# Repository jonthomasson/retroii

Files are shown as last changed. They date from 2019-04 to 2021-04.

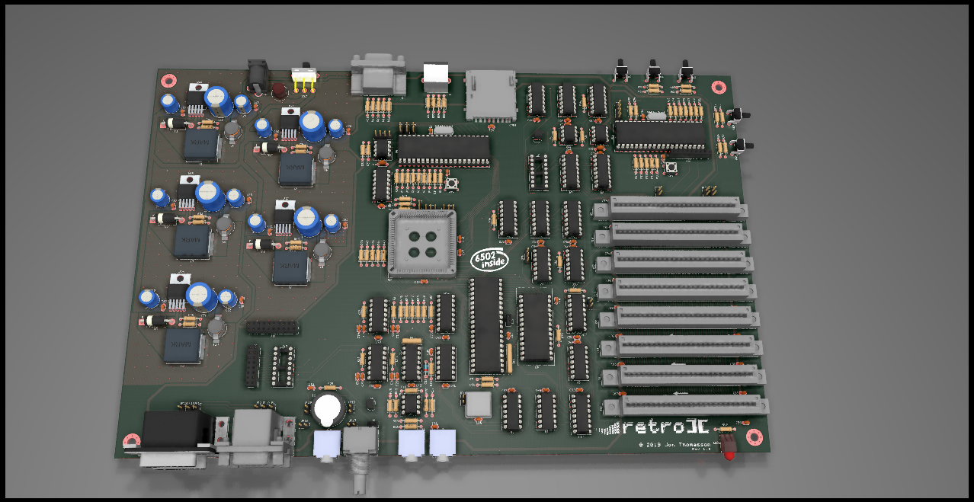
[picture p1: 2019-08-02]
rev1.a/retroii/pics/retroii_3d_front.png

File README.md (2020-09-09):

# retroii
Retro ][ is a 6502 based computer based off of the Apple ][. 

Growing up in the 80's I was part of an amazing and special time for computers. Every school I remember had a computer lab loaded with Apple ]['s running such iconic games as Oregon Trail, Odell Lake, and Number Munchers. My mom was a school teacher and somehow we were lucky enough to actually buy an Apple ][ to use at home. That to me sparked an interest in computers and technology that has followed me all these many decades later. 

Towards the beginning of 2019 David Murray, best known as The 8 Bit Guy, posted a video where he described his dream computer. In his video David tells about his childhood, growing up with a VIC 20 computer, and how he missed the closeness to the hardware that those early 8 bit computers provided. David's video got me thinking, and made me ask the tough life question, "what was my dream computer growing up, and what would that look like today?". That question would eventually give way to a year long project I called RETRO ][. The name Retro ][ came as a result of it being inspired and compatible with the original Apple ][, but also because it is a descendant of my first 6502 computer I built in 2015 which was called Retro 1. Retro 1 was similar to the Apple 1, with basically a terminal window to type in BASIC programs. With Retro ][ I wanted to add graphics. I used the Parallax Propeller for video generation in Retro 1, and I knew it could handle the task of more video processing. This is why I'm using it again in Retro ][.

Some basic design decisions for the project. I wanted it to feel like an 80's era computer, with the big beefy through hole components. I wanted it to be simple to understand and easy to program. I wanted it to be made from off the shelf parts that are still being produced today. I wanted it to have at least VGA output so that it could be connected to modern monitors. And for storage I wanted to be able to use a simple SD card. At its core, I wanted this project to be about learning. I wanted something that could give my kids the same sort of experience I had with the Apple ][ so long ago. The simplicity of being able to flip a bit at a ram location and see it result in drawing a pixel on the screen was eye opening to me as a youngster, and I was hoping to replicate that experience now with my own kids.

To meet my design decisions I needed to make a few changes to the original Apple ][ schematic. There were a number of components that were no longer made, like the keyboard encoder, the quad 558 timer, the RAM chips, etc. In addition the timing circuitry needed to be reworked to accommodate the new video requirements. The Apple ][ timing was tightly coupled with the video signal, the RAM refresh rates, as well as the keyboard multiplexer. I wanted to simplify all of this by feeding a simple 1MHz clock into all the key timing circuits. Later on I programmed the Parallax Propeller to take care of the timing. This enabled me to not only stop or single step the clock, but I could overclock the computer as well. I found that the max rate I could reliably get was around 4MHz. At the heart of Retro ][ is a WDC 65C02. I had to modify the original Apple ][ address decoding scheme a bit in order to get it to work for this project. By using the same address decoding as the original Apple ][ I'm able to run the same programs. I got rid of the DRAM and instead used a single 64K dual port static RAM. By using dual port ram, I can easily share the needed video RAM with the Propeller without having to worry about DMA. 

I have two Parallax Propellers in Retro ][. One is solely responsible for video. It simply reads from the video RAM and outputs a VGA signal. The other Propeller is in charge of routines related to the PS/2 keyboard, SD Card, and clock signals. The two Propeller's communicate with one another over an I2C bus. The Propeller ended up being a great fit for this project due to how it can easily handle many parallel processes at once. Instead of using interrupt routines like traditional microcontrollers, the Propeller has what are called "cogs". These cogs are basically tiny single core processes that can run independently. There's 8 cogs in each Propeller. The ability to handle these parallel processes make the Propeller unique in that it's easily programmed like a traditional microcontroller, but you can take advantage of running things in parallel similar to what an FPGA could do.

For the power supply, I wanted to support the same voltages as the original Apple ][ (+5v, -5v, +12v, -12v) as well as 3.3v to power the Propeller's. I settled on the LM2576. I liked the flexibility that the LM2576 provided. It was able to meet the current demands of the project, and came in an easily solderable through whole version. I did find that there was a large inrush current when first applying power, especially for the +12/-12 supply. I'm going to try and rectify this in the next revision.

The last large part of this project are the peripherals. I wanted it to have the same options for expansion as the original Apple ][. I have 8 expansion slots, compatible with existing Apple ][ cards. In addition there are two DB9 Apple ][ joystick ports, as well as two DB15 Gameports. 

For sound output, there's a built in speaker, as well as a headphone jack and a volume control knob to turn the game sounds down when playing at night or around other people. There's also a cassette out/in jack for loading programs on and saving programs to a device like a cassette, or these days a smart phone etc. 

That's it for now! I'll post more project updates as I have time. If you're interested, please make sure and follow my project here on Hackaday, as well as subscribe to my Youtube feed.

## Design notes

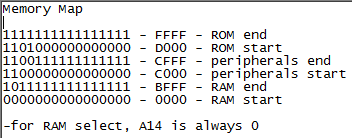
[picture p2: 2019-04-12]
rev1.a/retroii/pics/memory_map.PNG

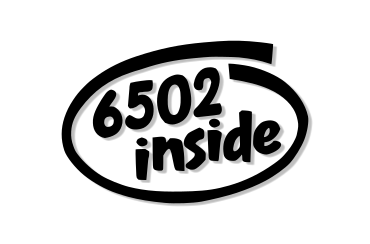
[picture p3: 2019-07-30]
rev1.a/retroii/pics/6502_inside.png

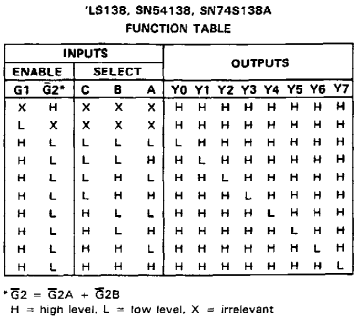
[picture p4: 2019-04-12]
rev1.a/retroii/pics/ls138_ft.PNG

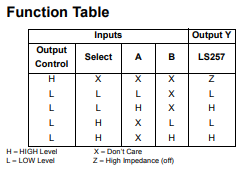
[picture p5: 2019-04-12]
rev1.a/retroii/pics/ls257_ft.PNG

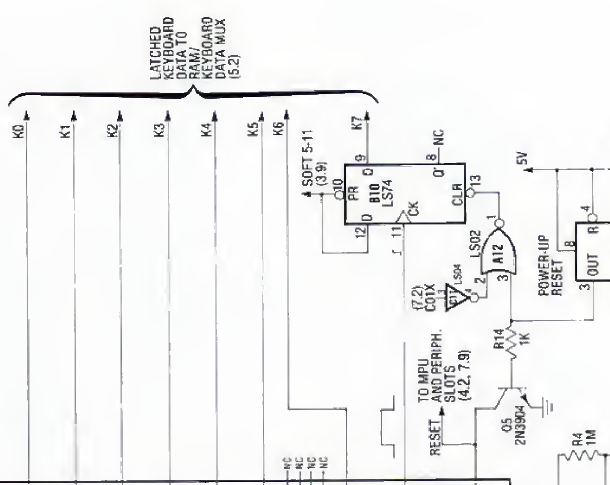
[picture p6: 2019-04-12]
rev1.a/retroii/pics/kbd_out.PNG

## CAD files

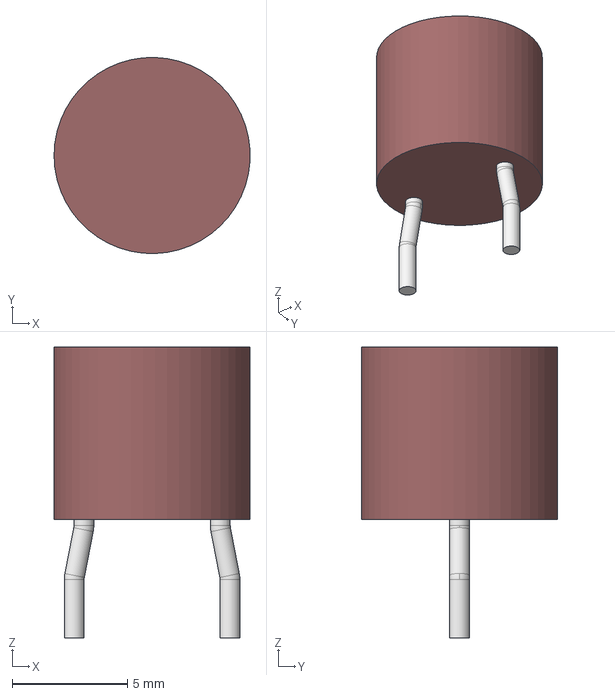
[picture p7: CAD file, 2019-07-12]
3d/FUS_LITTELFUSE_370.step
8.50 x 8.50 x 12.6 mm

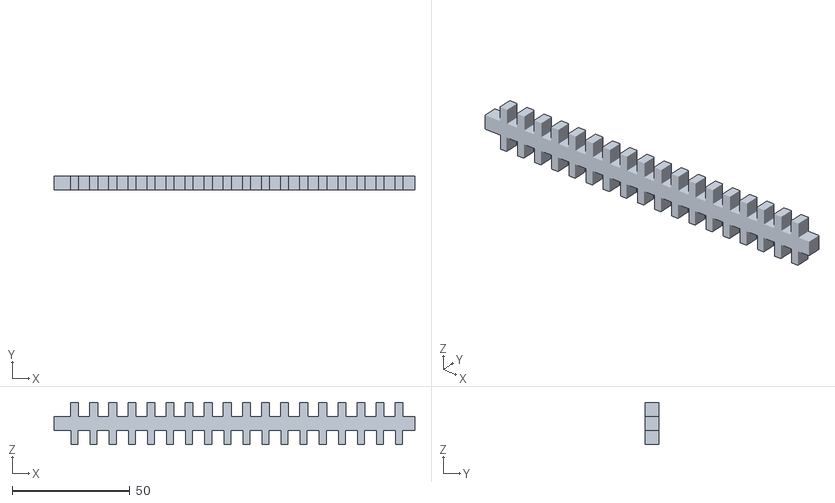
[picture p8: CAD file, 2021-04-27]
retroii-case/retroii_case_extension_v2 v2.stl
153.0 x 6.00 x 18.0

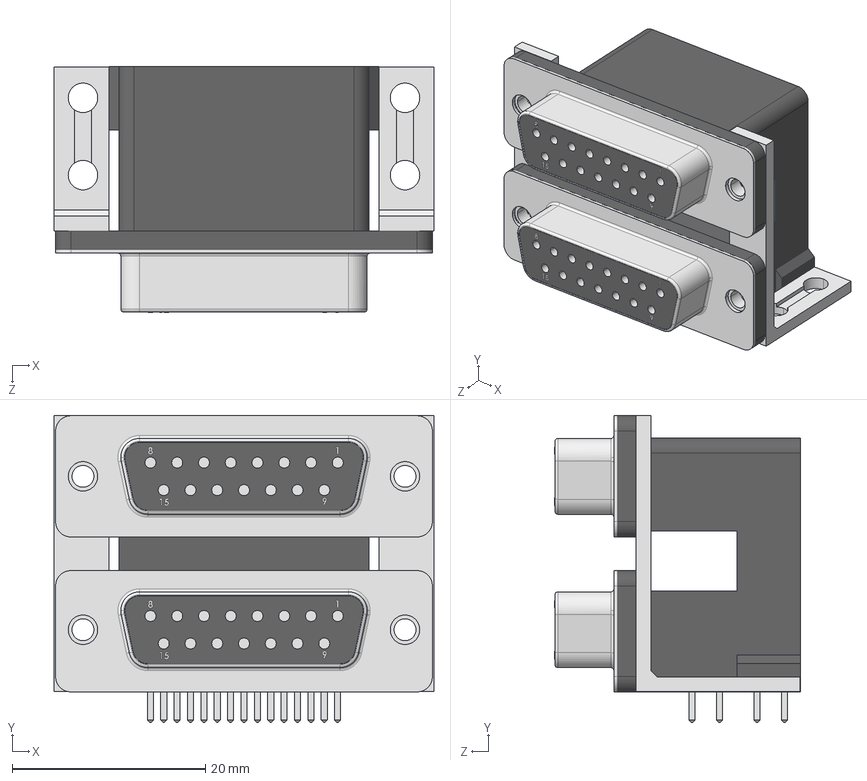
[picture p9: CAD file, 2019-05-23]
3d/189-015-513.STEP
39.3 x 31.8 x 25.4 mm

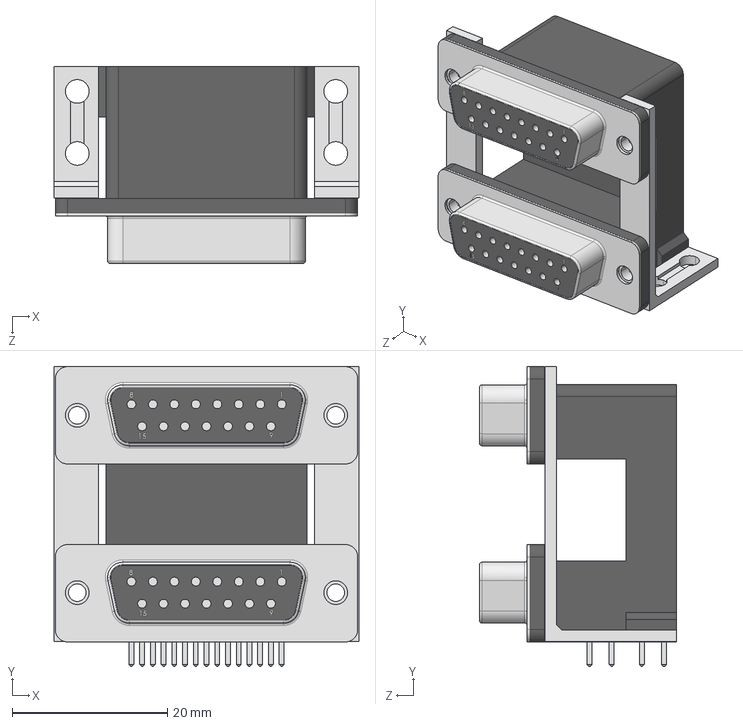
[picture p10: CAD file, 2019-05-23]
3d/179-015-513.STEP
39.3 x 38.7 x 25.4 mm

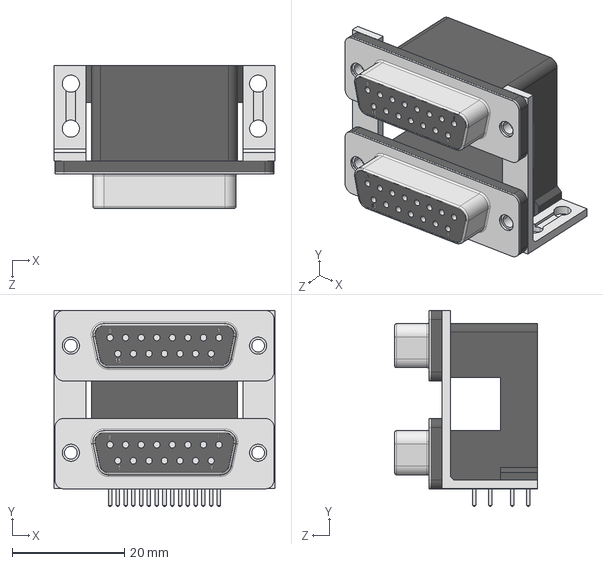
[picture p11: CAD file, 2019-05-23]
3d/178-015-513.STEP
39.3 x 35.0 x 25.4 mm

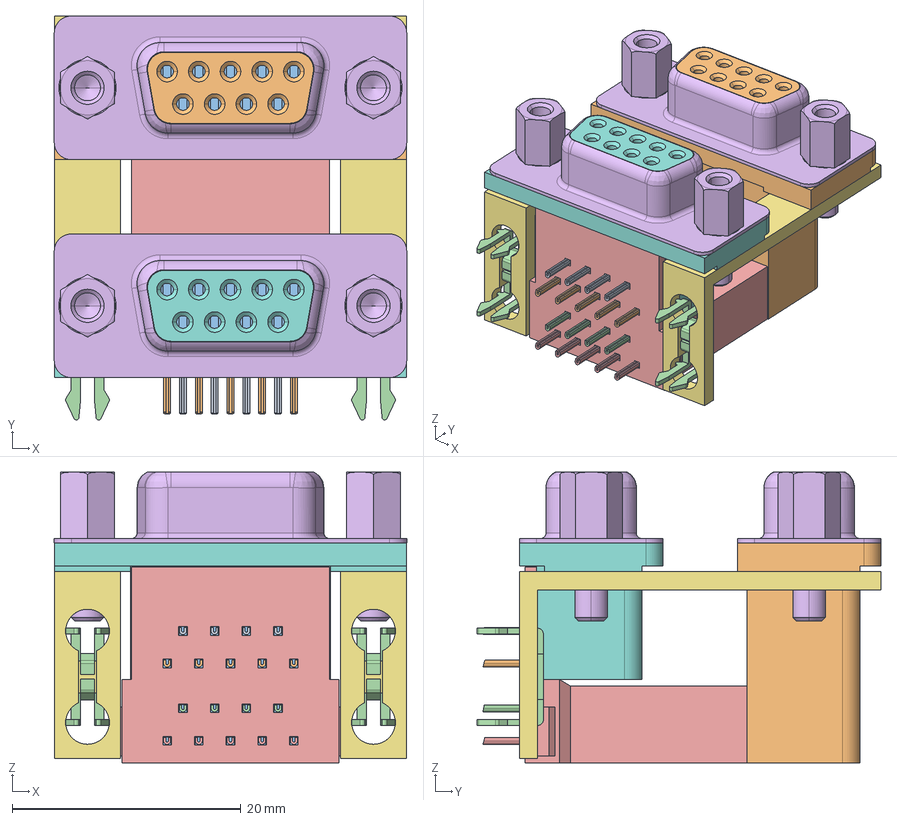
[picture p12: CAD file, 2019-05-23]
3d/L17H222X131.stp
30.8 x 35.3 x 25.4 mm
C-OD-B-138_37
C-OD-B-486_4
C-OD-B-329-_17 x 4
C-OD-B-330_16 x 5
H15S-SHELL_3 x 2
LZJ_12 x 2
C-OD-B-157_31
C-OD-B-315_13 x 4
C-OD-B-314_9 x 5
C-OD-B-206_6
YZ_9 x 2
LJZ_22
SCREW x 4

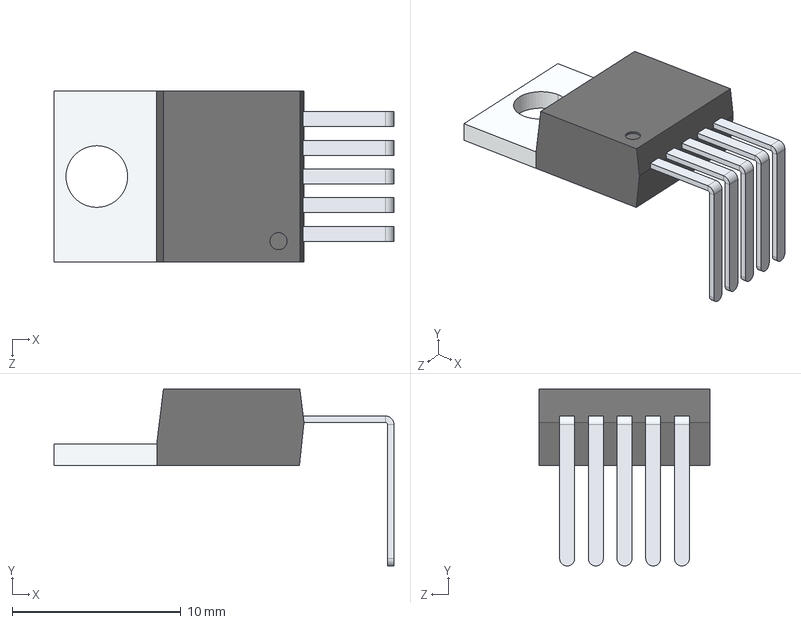
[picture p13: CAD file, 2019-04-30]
3d/TO-220-5.STEP
20.2 x 10.5 x 10.2 mm
User Library-TO-220-5_TO-220-5 Dissipador_Valor predeterminado
User Library-TO-220-5_TO-220-5 Corpo_Valor predeterminado
User Library-TO-220-5_TO-220-5 Terminal_Valor predeterminado x 5

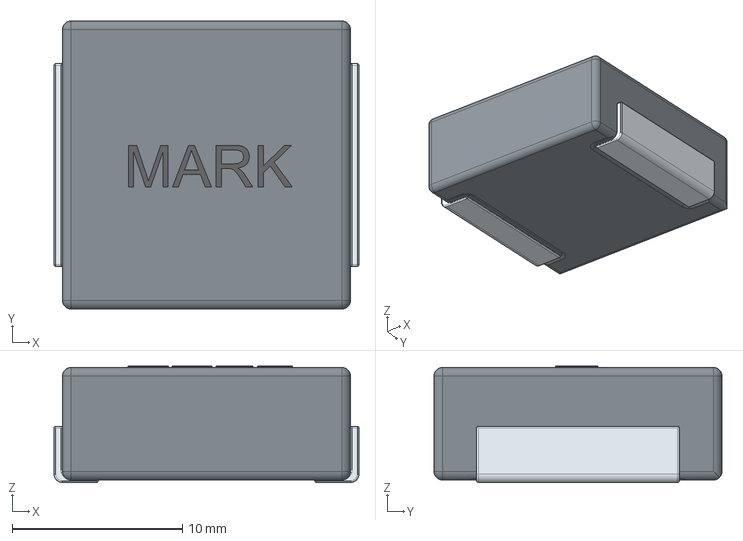
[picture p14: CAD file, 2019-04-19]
3d/SRP1770TA.stp
17.9 x 16.9 x 6.81 mm

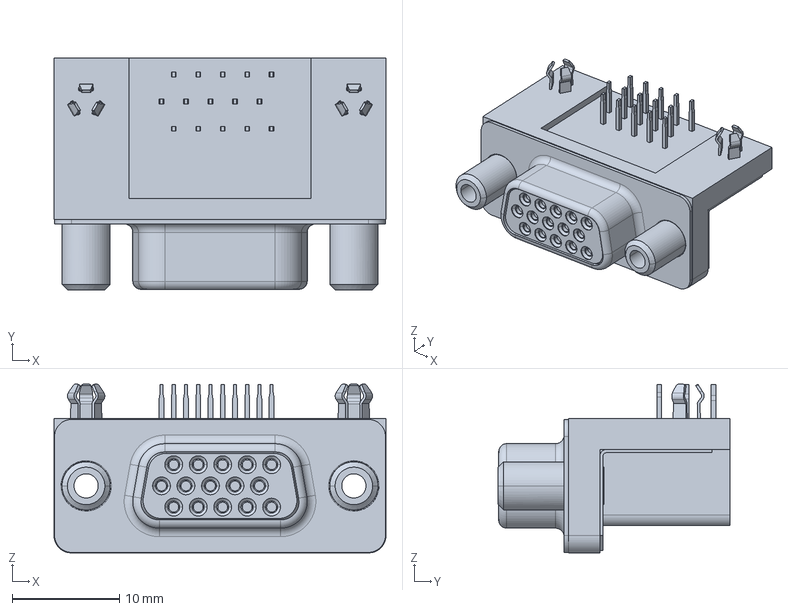
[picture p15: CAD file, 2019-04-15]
3d/Sicd15s13e6gv00lf.stp
31.0 x 21.6 x 15.8 mm

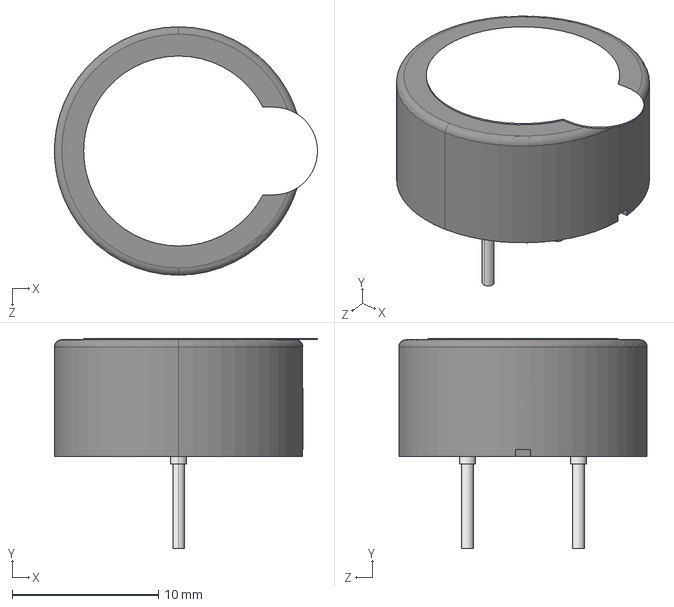
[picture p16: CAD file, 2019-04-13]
3d/CUI_CVS-1708.step
18.0 x 14.4 x 17.0 mm

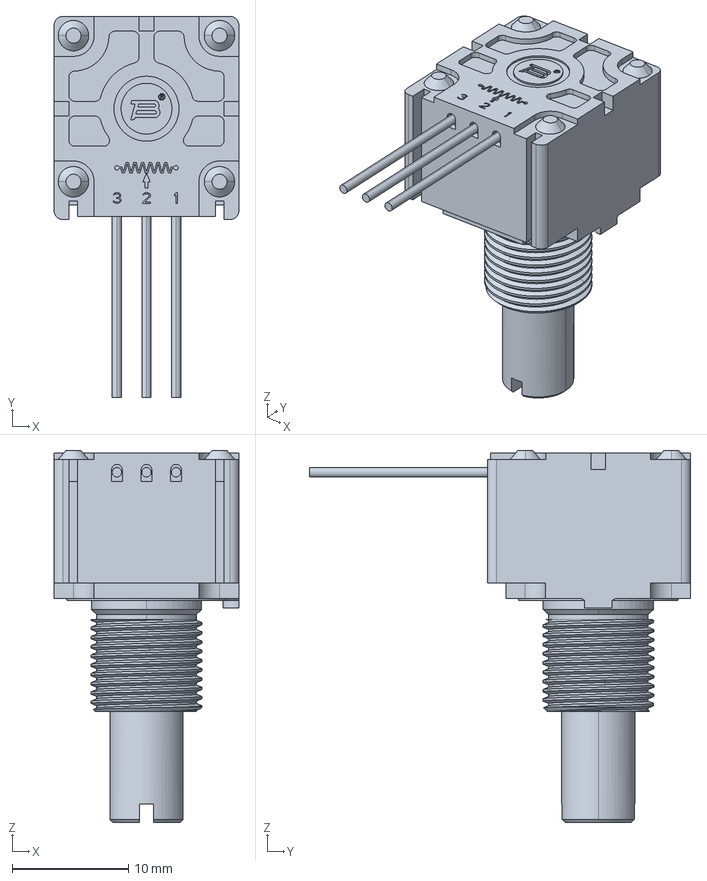
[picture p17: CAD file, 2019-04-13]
3d/91A1A-B24.stp
15.9 x 32.7 x 32.0 mm

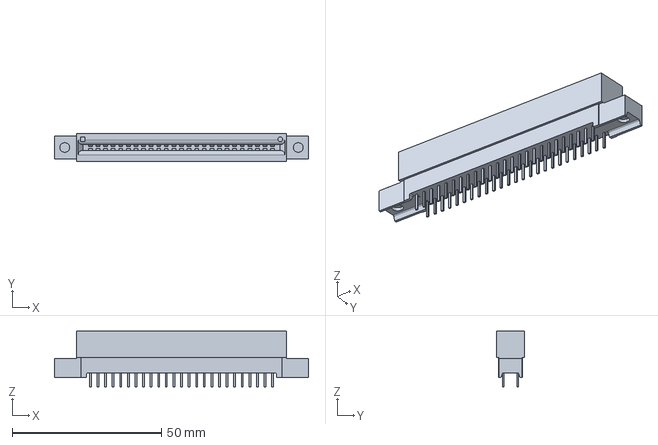
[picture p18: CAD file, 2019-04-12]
3d/c-5530841-5-b-3d.stp
85.0 x 9.35 x 18.7 mm

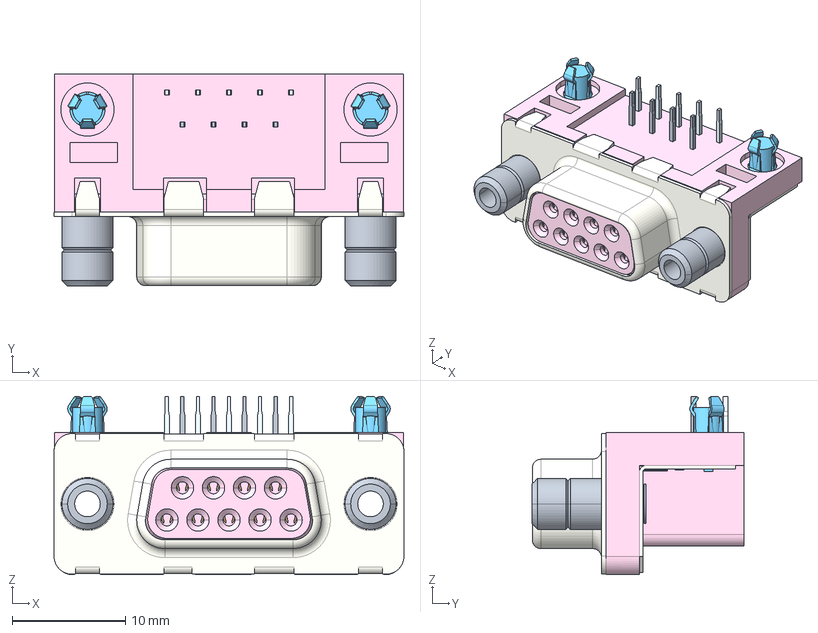
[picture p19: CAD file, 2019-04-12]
3d/sd09s33e6gv00lf.stp
30.9 x 18.8 x 15.8 mm

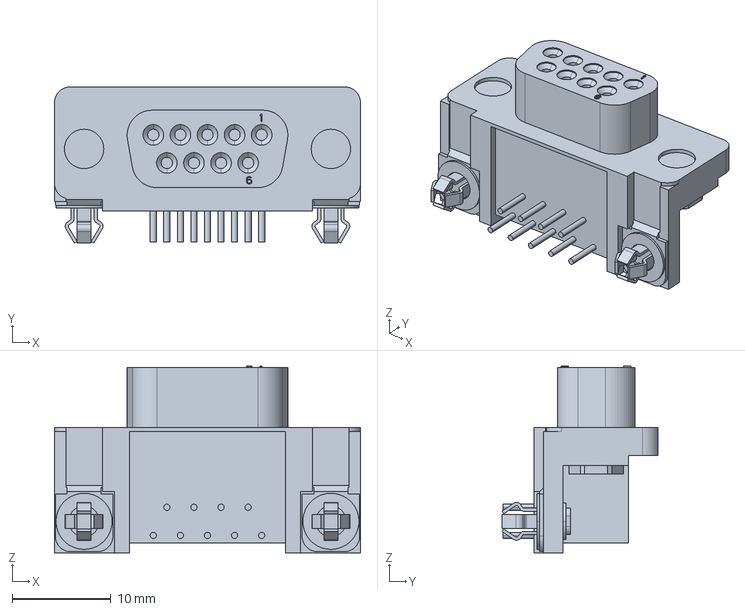
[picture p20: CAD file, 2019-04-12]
3d/c-5747844-04-o-3d.stp
31.0 x 15.8 x 18.9 mm

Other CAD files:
3d/D15S33E4GV00LFC.stp
3d/CONN_5747844-6.step

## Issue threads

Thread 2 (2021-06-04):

Power supply problem.

sillycony, 2021-06-04:
Hi Jon,

I am trying to make a copy of your RETROII. And indeed, there is a problem with the two negative power supplies. Have you been able to make progress on this subject?
I think I have found the reason for this dysfunction. The (positive) outputs of the regulators MUST NOT BE connected directly to the GND. In addition, a capacitor must be positioned between the general power supply of the card and the -12V and the -5V to correctly reference the negative power supplies.
I haven't tested this fix yet but the schema will need to be fixed anyway, as well as the Gerbers files.
Best regards.
Eric

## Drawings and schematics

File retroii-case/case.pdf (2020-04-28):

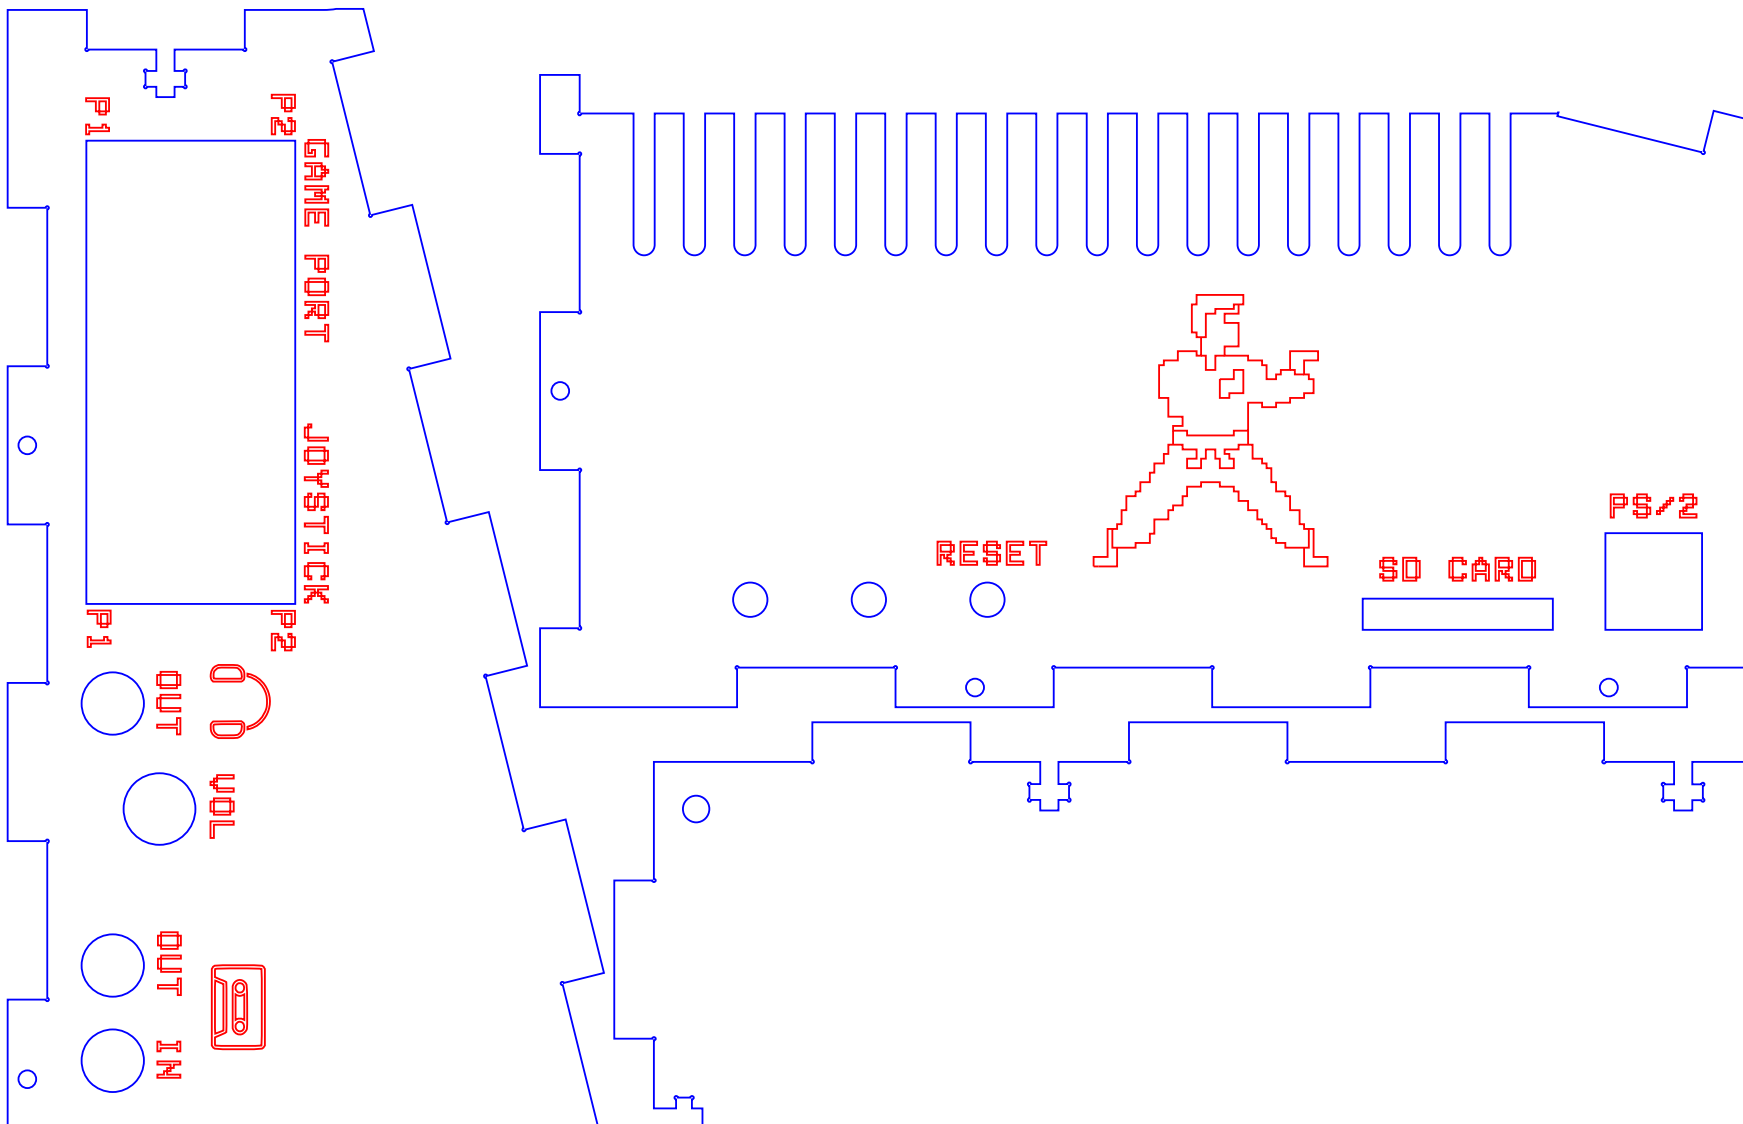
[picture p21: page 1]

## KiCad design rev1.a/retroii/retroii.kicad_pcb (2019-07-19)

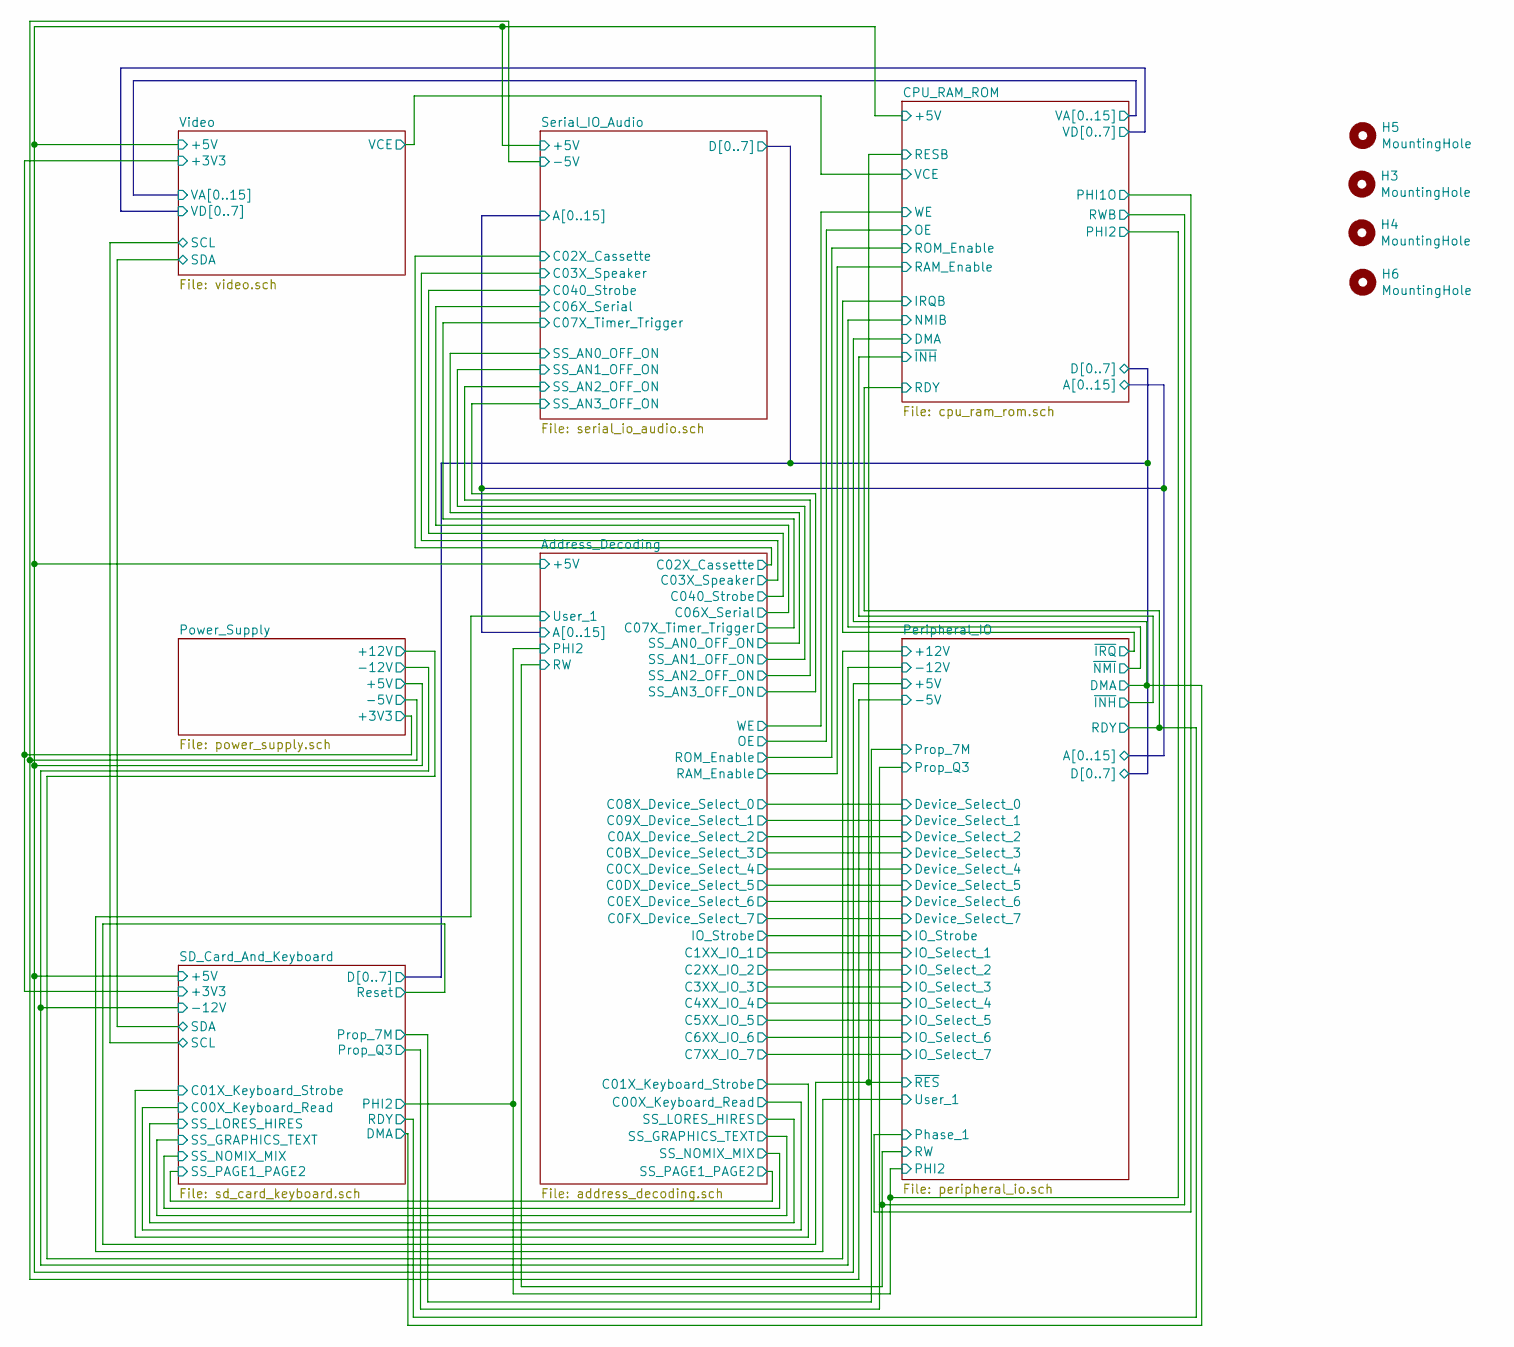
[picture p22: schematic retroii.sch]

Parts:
H3, H4, H5, H6: MountingHole; MountingHole_4.3mm_M4_Pad_Via

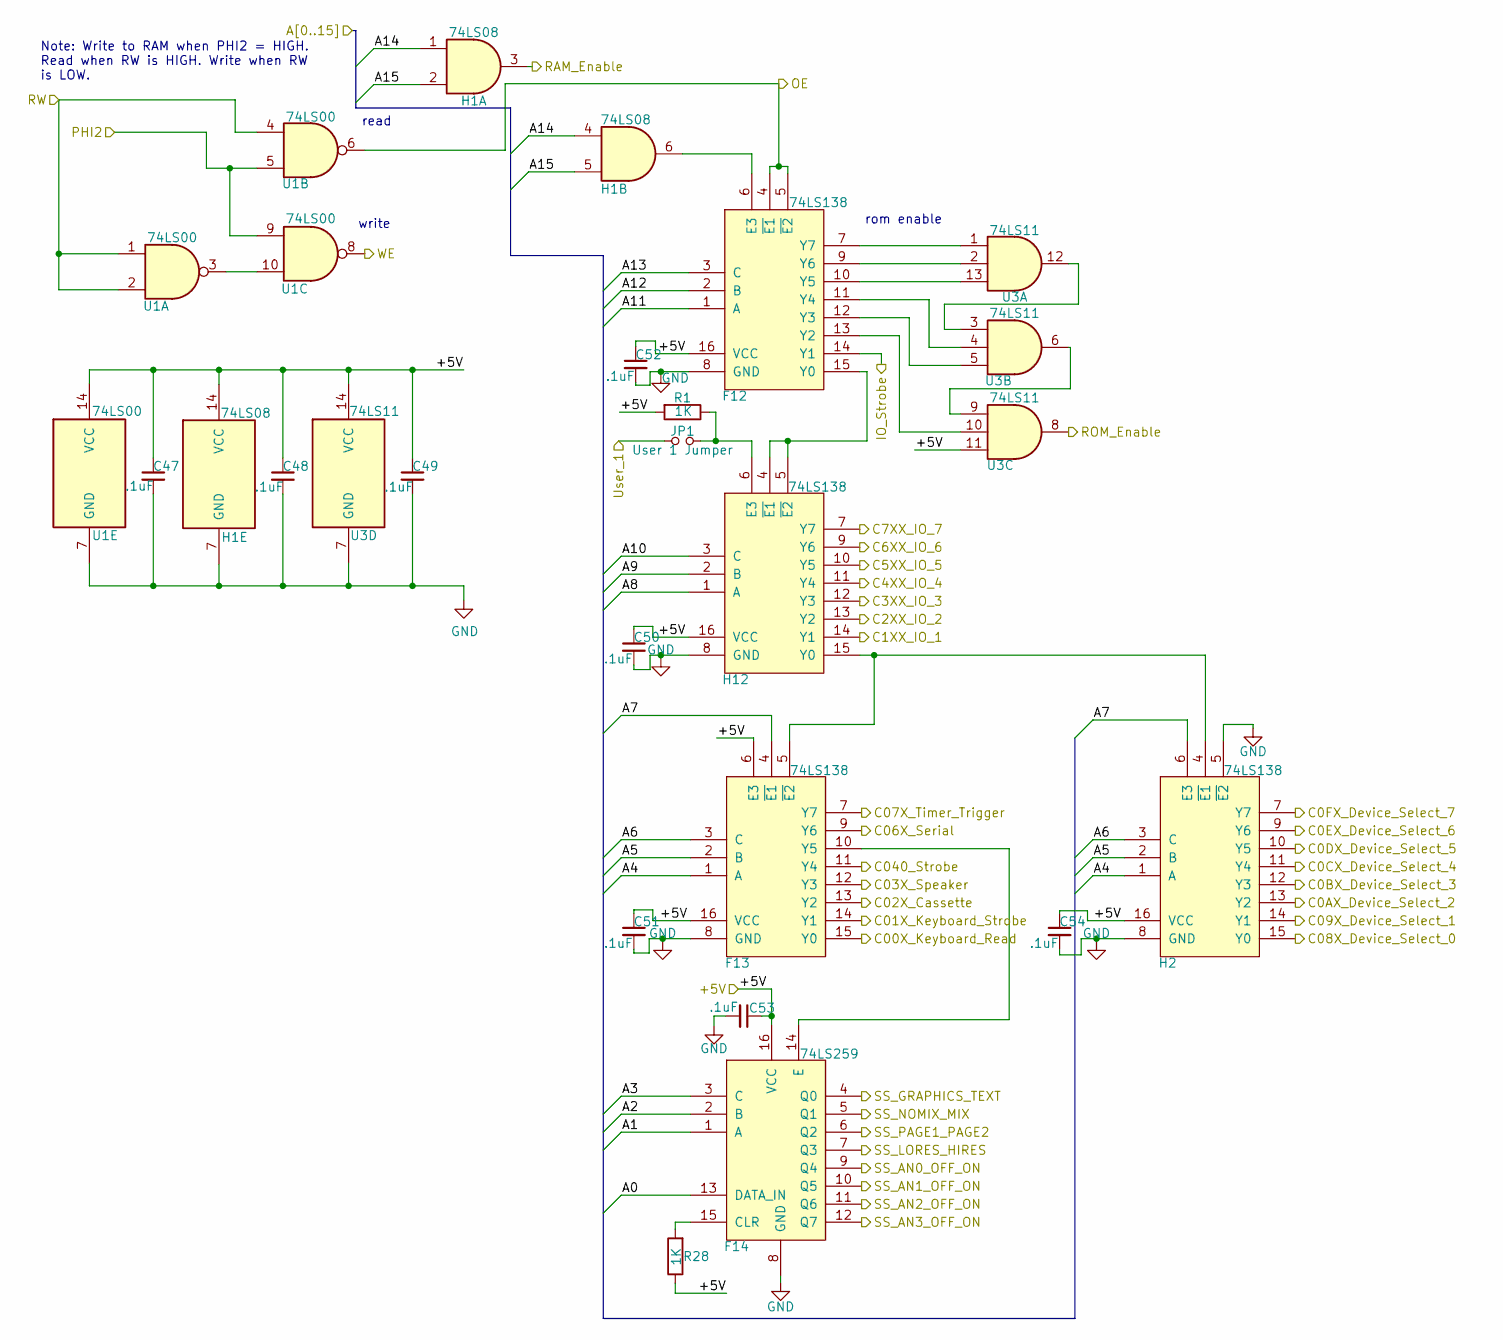
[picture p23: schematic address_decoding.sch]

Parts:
C47, C48, C49, C50, C51, C52, C53, C54: .1uF; C_Disc_D3.0mm_W2.0mm_P2.50mm
F12, F13: 74LS138; DIP-16_W7.62mm_Socket_LongPads
F14: 74LS259; DIP-16_W7.62mm_Socket_LongPads
H1: 74LS08; DIP-14_W7.62mm_Socket_LongPads
H2, H12: 74LS138; DIP-16_W7.62mm_Socket_LongPads
JP1: User 1 Jumper; PinHeader_1x02_P2.54mm_Vertical
R1, R28: 1K; R_Axial_DIN0207_L6.3mm_D2.5mm_P10.16mm_Horizontal
U1: 74LS00; DIP-14_W7.62mm_Socket_LongPads
U3: 74LS11; DIP-14_W7.62mm_Socket_LongPads

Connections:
/Address_Decoding/+5V: C47.1, C48.1, C49.1, C50.1, C51.1, C52.1, C53.1, C54.1, F12.16 (VCC), F13.6 (E3), F13.16 (VCC), F14.16 (VCC), H1.14 (VCC), H2.16 (VCC), H12.16 (VCC), R1.2, R28.1, U1.14 (VCC), U3.11, U3.14 (VCC); also elsewhere on the board
/Address_Decoding/A0: F14.13 (DATA_IN); also elsewhere on the board
/Address_Decoding/A1: F14.1 (A); also elsewhere on the board
/Address_Decoding/A2: F14.2 (B); also elsewhere on the board
/Address_Decoding/A3: F14.3 (C); also elsewhere on the board
/Address_Decoding/A4: F13.1 (A), H2.1 (A); also elsewhere on the board
/Address_Decoding/A5: F13.2 (B), H2.2 (B); also elsewhere on the board
/Address_Decoding/A6: F13.3 (C), H2.3 (C); also elsewhere on the board
/Address_Decoding/A7: F13.4 (~E1), H2.6 (E3); also elsewhere on the board
/Address_Decoding/A8: H12.1 (A); also elsewhere on the board
/Address_Decoding/A9: H12.2 (B); also elsewhere on the board
/Address_Decoding/A10: H12.3 (C); also elsewhere on the board
/Address_Decoding/A11: F12.1 (A); also elsewhere on the board
/Address_Decoding/A12: F12.2 (B); also elsewhere on the board
/Address_Decoding/A13: F12.3 (C); also elsewhere on the board
/Address_Decoding/A14: H1.1, H1.4; also elsewhere on the board
/Address_Decoding/A15: H1.2, H1.5; also elsewhere on the board
/Address_Decoding/C0AX_Device_Select_2: H2.13 (Y2); also elsewhere on the board
/Address_Decoding/C0BX_Device_Select_3: H2.12 (Y3); also elsewhere on the board
/Address_Decoding/C0CX_Device_Select_4: H2.11 (Y4); also elsewhere on the board
/Address_Decoding/C0DX_Device_Select_5: H2.10 (Y5); also elsewhere on the board
/Address_Decoding/C0EX_Device_Select_6: H2.9 (Y6); also elsewhere on the board
/Address_Decoding/C0FX_Device_Select_7: H2.7 (Y7); also elsewhere on the board
/Address_Decoding/C00X_Keyboard_Read: F13.15 (Y0); also elsewhere on the board
/Address_Decoding/C1XX_IO_1: H12.14 (Y1); also elsewhere on the board
/Address_Decoding/C01X_Keyboard_Strobe: F13.14 (Y1); also elsewhere on the board
/Address_Decoding/C2XX_IO_2: H12.13 (Y2); also elsewhere on the board
/Address_Decoding/C02X_Cassette: F13.13 (Y2); also elsewhere on the board
/Address_Decoding/C3XX_IO_3: H12.12 (Y3); also elsewhere on the board
/Address_Decoding/C03X_Speaker: F13.12 (Y3); also elsewhere on the board
/Address_Decoding/C4XX_IO_4: H12.11 (Y4); also elsewhere on the board
/Address_Decoding/C5XX_IO_5: H12.10 (Y5); also elsewhere on the board
/Address_Decoding/C6XX_IO_6: H12.9 (Y6); also elsewhere on the board
/Address_Decoding/C06X_Serial: F13.9 (Y6); also elsewhere on the board
/Address_Decoding/C7XX_IO_7: H12.7 (Y7); also elsewhere on the board
/Address_Decoding/C07X_Timer_Trigger: F13.7 (Y7); also elsewhere on the board
/Address_Decoding/C08X_Device_Select_0: H2.15 (Y0); also elsewhere on the board
/Address_Decoding/C09X_Device_Select_1: H2.14 (Y1); also elsewhere on the board
/Address_Decoding/C040_Strobe: F13.11 (Y4); also elsewhere on the board
/Address_Decoding/IO_Strobe: F12.14 (Y1); also elsewhere on the board
/Address_Decoding/OE: F12.4 (~E1), F12.5 (~E2), U1.6; also elsewhere on the board
/Address_Decoding/PHI2: U1.5, U1.9; also elsewhere on the board
/Address_Decoding/RAM_Enable: H1.3; also elsewhere on the board
/Address_Decoding/ROM_Enable: U3.8; also elsewhere on the board
/Address_Decoding/RW: U1.1, U1.2, U1.4; also elsewhere on the board
/Address_Decoding/SS_AN0_OFF_ON: F14.9 (Q4); also elsewhere on the board
/Address_Decoding/SS_AN1_OFF_ON: F14.10 (Q5); also elsewhere on the board
/Address_Decoding/SS_AN2_OFF_ON: F14.11 (Q6); also elsewhere on the board
/Address_Decoding/SS_AN3_OFF_ON: F14.12 (Q7); also elsewhere on the board
/Address_Decoding/SS_GRAPHICS_TEXT: F14.4 (Q0); also elsewhere on the board
/Address_Decoding/SS_LORES_HIRES: F14.7 (Q3); also elsewhere on the board
/Address_Decoding/SS_NOMIX_MIX: F14.5 (Q1); also elsewhere on the board
/Address_Decoding/SS_PAGE1_PAGE2: F14.6 (Q2); also elsewhere on the board
/Address_Decoding/User_1: JP1.1; also elsewhere on the board
/Address_Decoding/WE: U1.8; also elsewhere on the board
GND: C47.2, C48.2, C49.2, C50.2, C51.2, C52.2, C53.2, C54.2, F12.8 (GND), F13.8 (GND), F14.8 (GND), H1.7 (GND), H2.5 (~E2), H2.8 (GND), H12.8 (GND), U1.7 (GND), U3.7 (GND); also elsewhere on the board
unnamed: F12.6 (E3), H1.6
unnamed: F12.7 (Y7), U3.1
unnamed: F12.9 (Y6), U3.2
unnamed: F12.10 (Y5), U3.13
unnamed: F12.11 (Y4), U3.4
unnamed: F12.12 (Y3), U3.5
unnamed: F12.13 (Y2), U3.10
unnamed: F12.15 (Y0), H12.4 (~E1), H12.5 (~E2)
unnamed: F13.5 (~E2), H2.4 (~E1), H12.15 (Y0)
unnamed: F13.10 (Y5), F14.14 (E)
unnamed: F14.15 (CLR), R28.2
unnamed: H12.6 (E3), JP1.2, R1.1
unnamed: U1.3, U1.10
unnamed: U3.6, U3.9
unnamed: U3.3, U3.12

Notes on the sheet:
read
write
rom enable
Note: Write to RAM when PHI2 = HIGH. Read when RW is HIGH. Write when RW is LOW.

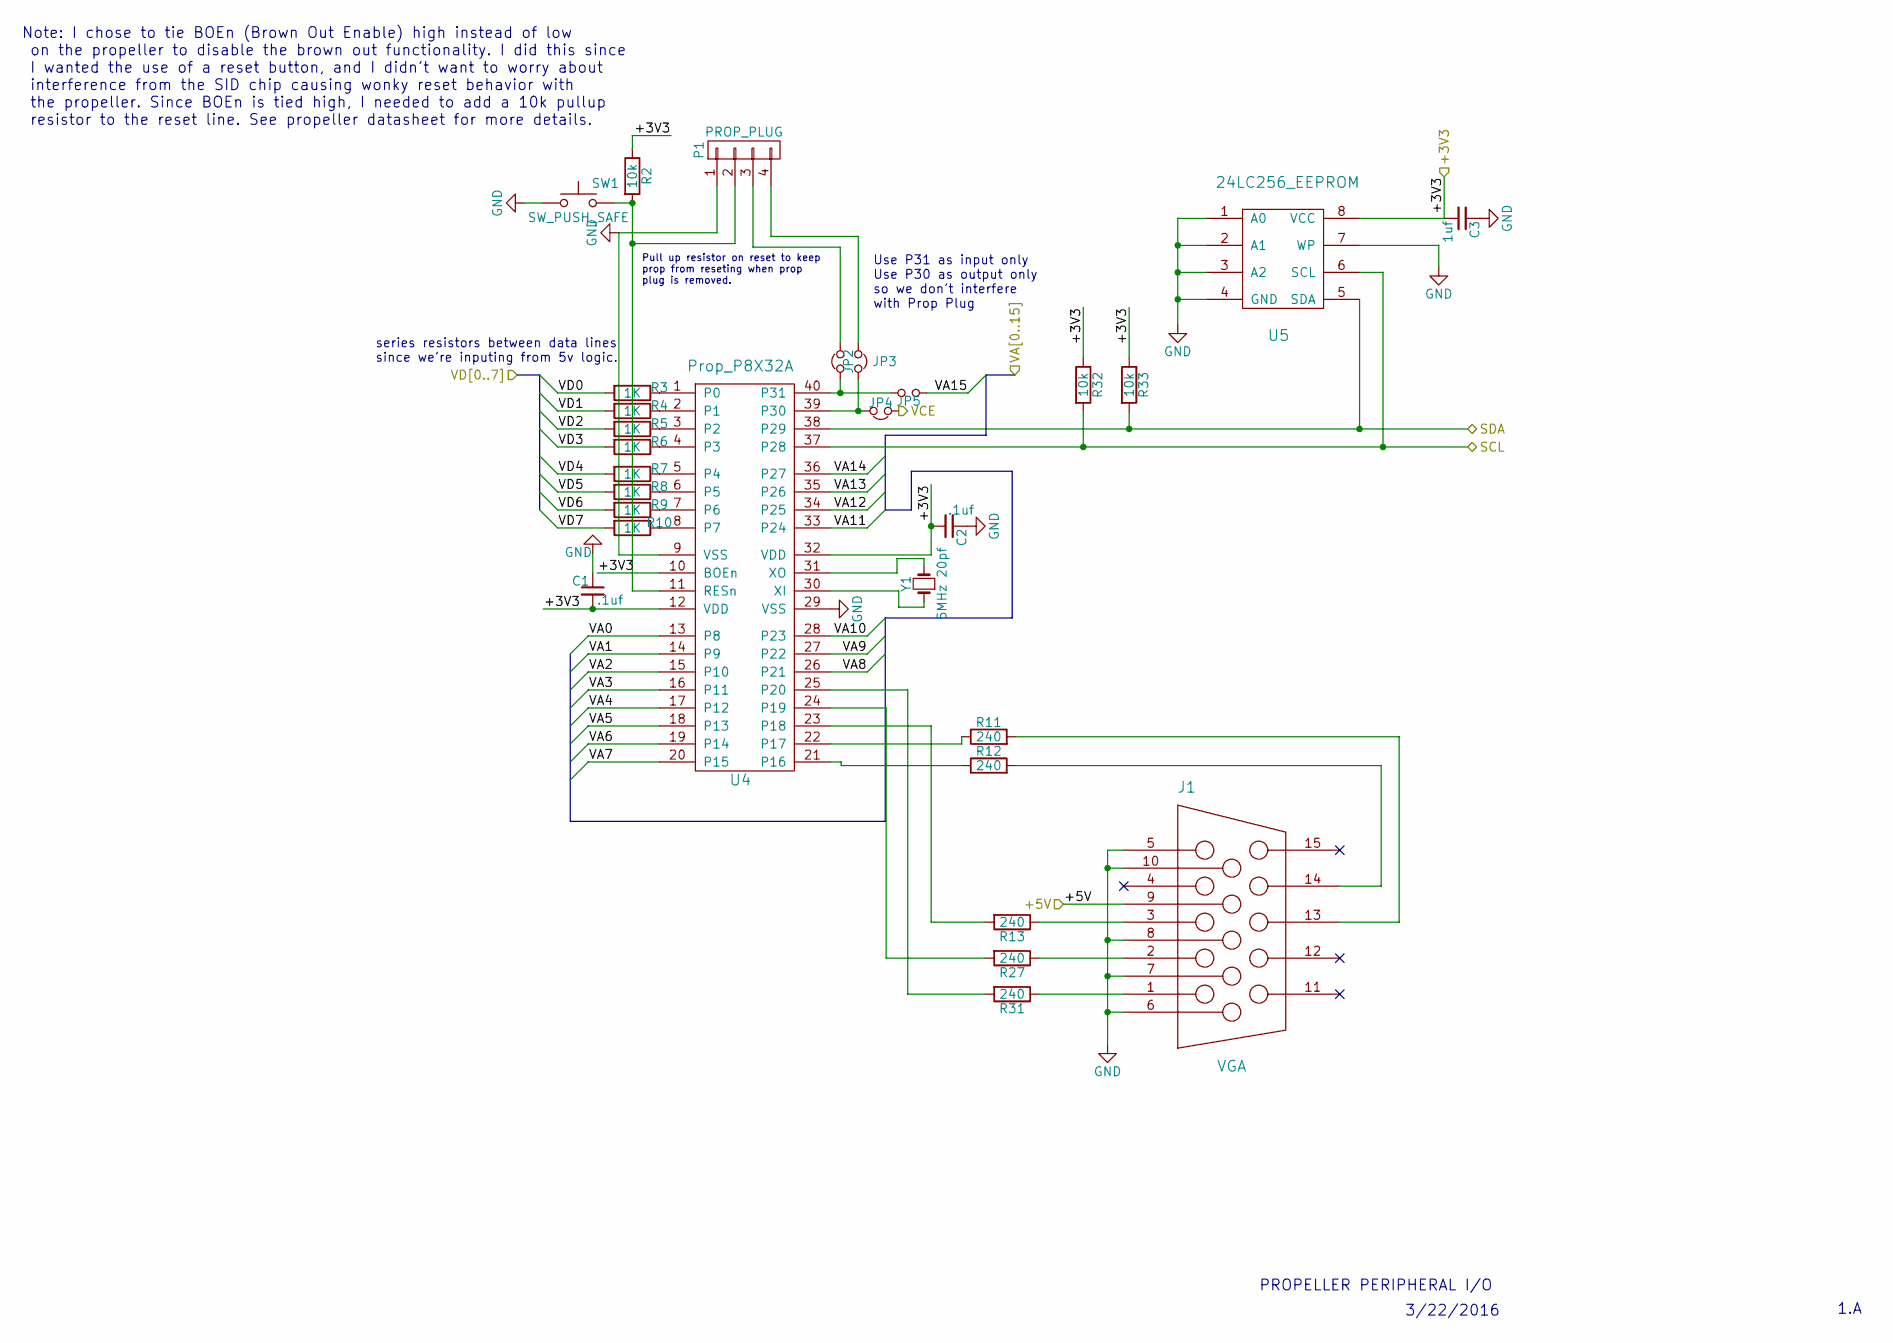
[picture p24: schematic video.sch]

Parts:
C1, C2: .1uf; C_Disc_D3.0mm_W2.0mm_P2.50mm
C3: 1uf; C_Disc_D4.7mm_W2.5mm_P5.00mm
J1: VGA; Amphenol_ICD15S13E6GV00LF
JP2, JP3, JP4, JP5: Jumper_NO_Small; PinHeader_1x02_P2.54mm_Vertical
P1: PROP_PLUG; PinHeader_1x04_P2.54mm_Vertical
R2, R32, R33: 10k; R_Axial_DIN0207_L6.3mm_D2.5mm_P10.16mm_Horizontal
R3, R4, R5, R6, R7, R8, R9, R10: 1K; R_Axial_DIN0207_L6.3mm_D2.5mm_P10.16mm_Horizontal
R11, R12, R13, R27, R31: 240; R_Axial_DIN0207_L6.3mm_D2.5mm_P10.16mm_Horizontal
SW1: SW_PUSH_SAFE; TE_1825910-6
U4: Prop_P8X32A; DIP-40_W15.24mm_Socket_LongPads
U5: 24LC256_EEPROM; DIP-8_W7.62mm_Socket_LongPads
Y1: 5MHz 20pf; crystal_hc-49s

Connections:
/Address_Decoding/+5V: J1.9 (KEY/PWR); also elsewhere on the board
/CPU_RAM_ROM/VA0: U4.13 (P8); also elsewhere on the board
/CPU_RAM_ROM/VA1: U4.14 (P9); also elsewhere on the board
/CPU_RAM_ROM/VA2: U4.15 (P10); also elsewhere on the board
/CPU_RAM_ROM/VA3: U4.16 (P11); also elsewhere on the board
/CPU_RAM_ROM/VA4: U4.17 (P12); also elsewhere on the board
/CPU_RAM_ROM/VA5: U4.18 (P13); also elsewhere on the board
/CPU_RAM_ROM/VA6: U4.19 (P14); also elsewhere on the board
/CPU_RAM_ROM/VA7: U4.20 (P15); also elsewhere on the board
/CPU_RAM_ROM/VA8: U4.26 (P21); also elsewhere on the board
/CPU_RAM_ROM/VA9: U4.27 (P22); also elsewhere on the board
/CPU_RAM_ROM/VA10: U4.28 (P23); also elsewhere on the board
/CPU_RAM_ROM/VA11: U4.33 (P24); also elsewhere on the board
/CPU_RAM_ROM/VA12: U4.34 (P25); also elsewhere on the board
/CPU_RAM_ROM/VA13: U4.35 (P26); also elsewhere on the board
/CPU_RAM_ROM/VA14: U4.36 (P27); also elsewhere on the board
/CPU_RAM_ROM/VA15: JP5.2; also elsewhere on the board
/CPU_RAM_ROM/VCE: JP4.1; also elsewhere on the board
/CPU_RAM_ROM/VD0: R3.2; also elsewhere on the board
/CPU_RAM_ROM/VD1: R4.2; also elsewhere on the board
/CPU_RAM_ROM/VD2: R5.2; also elsewhere on the board
/CPU_RAM_ROM/VD3: R6.2; also elsewhere on the board
/CPU_RAM_ROM/VD4: R7.2; also elsewhere on the board
/CPU_RAM_ROM/VD5: R8.2; also elsewhere on the board
/CPU_RAM_ROM/VD6: R9.2; also elsewhere on the board
/CPU_RAM_ROM/VD7: R10.2; also elsewhere on the board
/Power_Supply/+3V3: C1.2, C2.2, C3.2, R2.1, R32.1, R33.1, U4.10 (BOEn), U4.12 (VDD), U4.32 (VDD), U5.8 (VCC); also elsewhere on the board
/SD_Card_And_Keyboard/SCL: R32.2, U4.37 (P28), U5.6 (SCL); also elsewhere on the board
/SD_Card_And_Keyboard/SDA: R33.2, U4.38 (P29), U5.5 (SDA); also elsewhere on the board
GND: C1.1, C2.1, C3.1, J1.5 (GND_HSYNC), J1.6 (RED_RTN), J1.7 (GREEN_RTN), J1.8 (BLUE_RTN), J1.10 (GND_VSYNC), P1.1, SW1.1, U4.9 (VSS), U4.29 (VSS), U5.1 (A0), U5.2 (A1), U5.3 (A2), U5.4 (GND), U5.7 (WP); also elsewhere on the board
unnamed: J1.1 (RED), R31.1
unnamed: J1.2 (GREEN), R27.1
unnamed: J1.3 (BLUE), R13.1
unnamed: J1.13 (HSYNC), R11.2
unnamed: J1.14 (VSYNC), R12.2
unnamed: JP2.1, JP5.1, U4.40 (P31)
unnamed: JP2.2, P1.3
unnamed: JP3.1, P1.4
unnamed: JP3.2, JP4.2, U4.39 (P30)
unnamed: P1.2, R2.2, SW1.4, U4.11 (RESn)
unnamed: R3.1, U4.1 (P0)
unnamed: R4.1, U4.2 (P1)
unnamed: R5.1, U4.3 (P2)
unnamed: R6.1, U4.4 (P3)
unnamed: R7.1, U4.5 (P4)
unnamed: R8.1, U4.6 (P5)
unnamed: R9.1, U4.7 (P6)
unnamed: R10.1, U4.8 (P7)
unnamed: R11.1, U4.22 (P17)
unnamed: R12.1, U4.21 (P16)
unnamed: R13.2, U4.23 (P18)
unnamed: R27.2, U4.24 (P19)
unnamed: R31.2, U4.25 (P20)
unnamed: U4.30 (XI), Y1.1
unnamed: U4.31 (XO), Y1.2

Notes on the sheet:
Note: I chose to tie BOEn (Brown Out Enable) high instead of low on the propeller to disable the brown out functionality. I did this since I wanted the use of a reset button, and I didn't want to worry about interference from the SID chip causing wonky reset behavior with the propeller. Since BOEn 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
Pull up resistor on reset to keep prop from reseting when prop plug is removed.
PROPELLER PERIPHERAL I/O
3/22/2016
1.A
Use P31 as input only Use P30 as output only so we don't interfere with Prop Plug
series resistors between data lines since we're inputing from 5v logic.

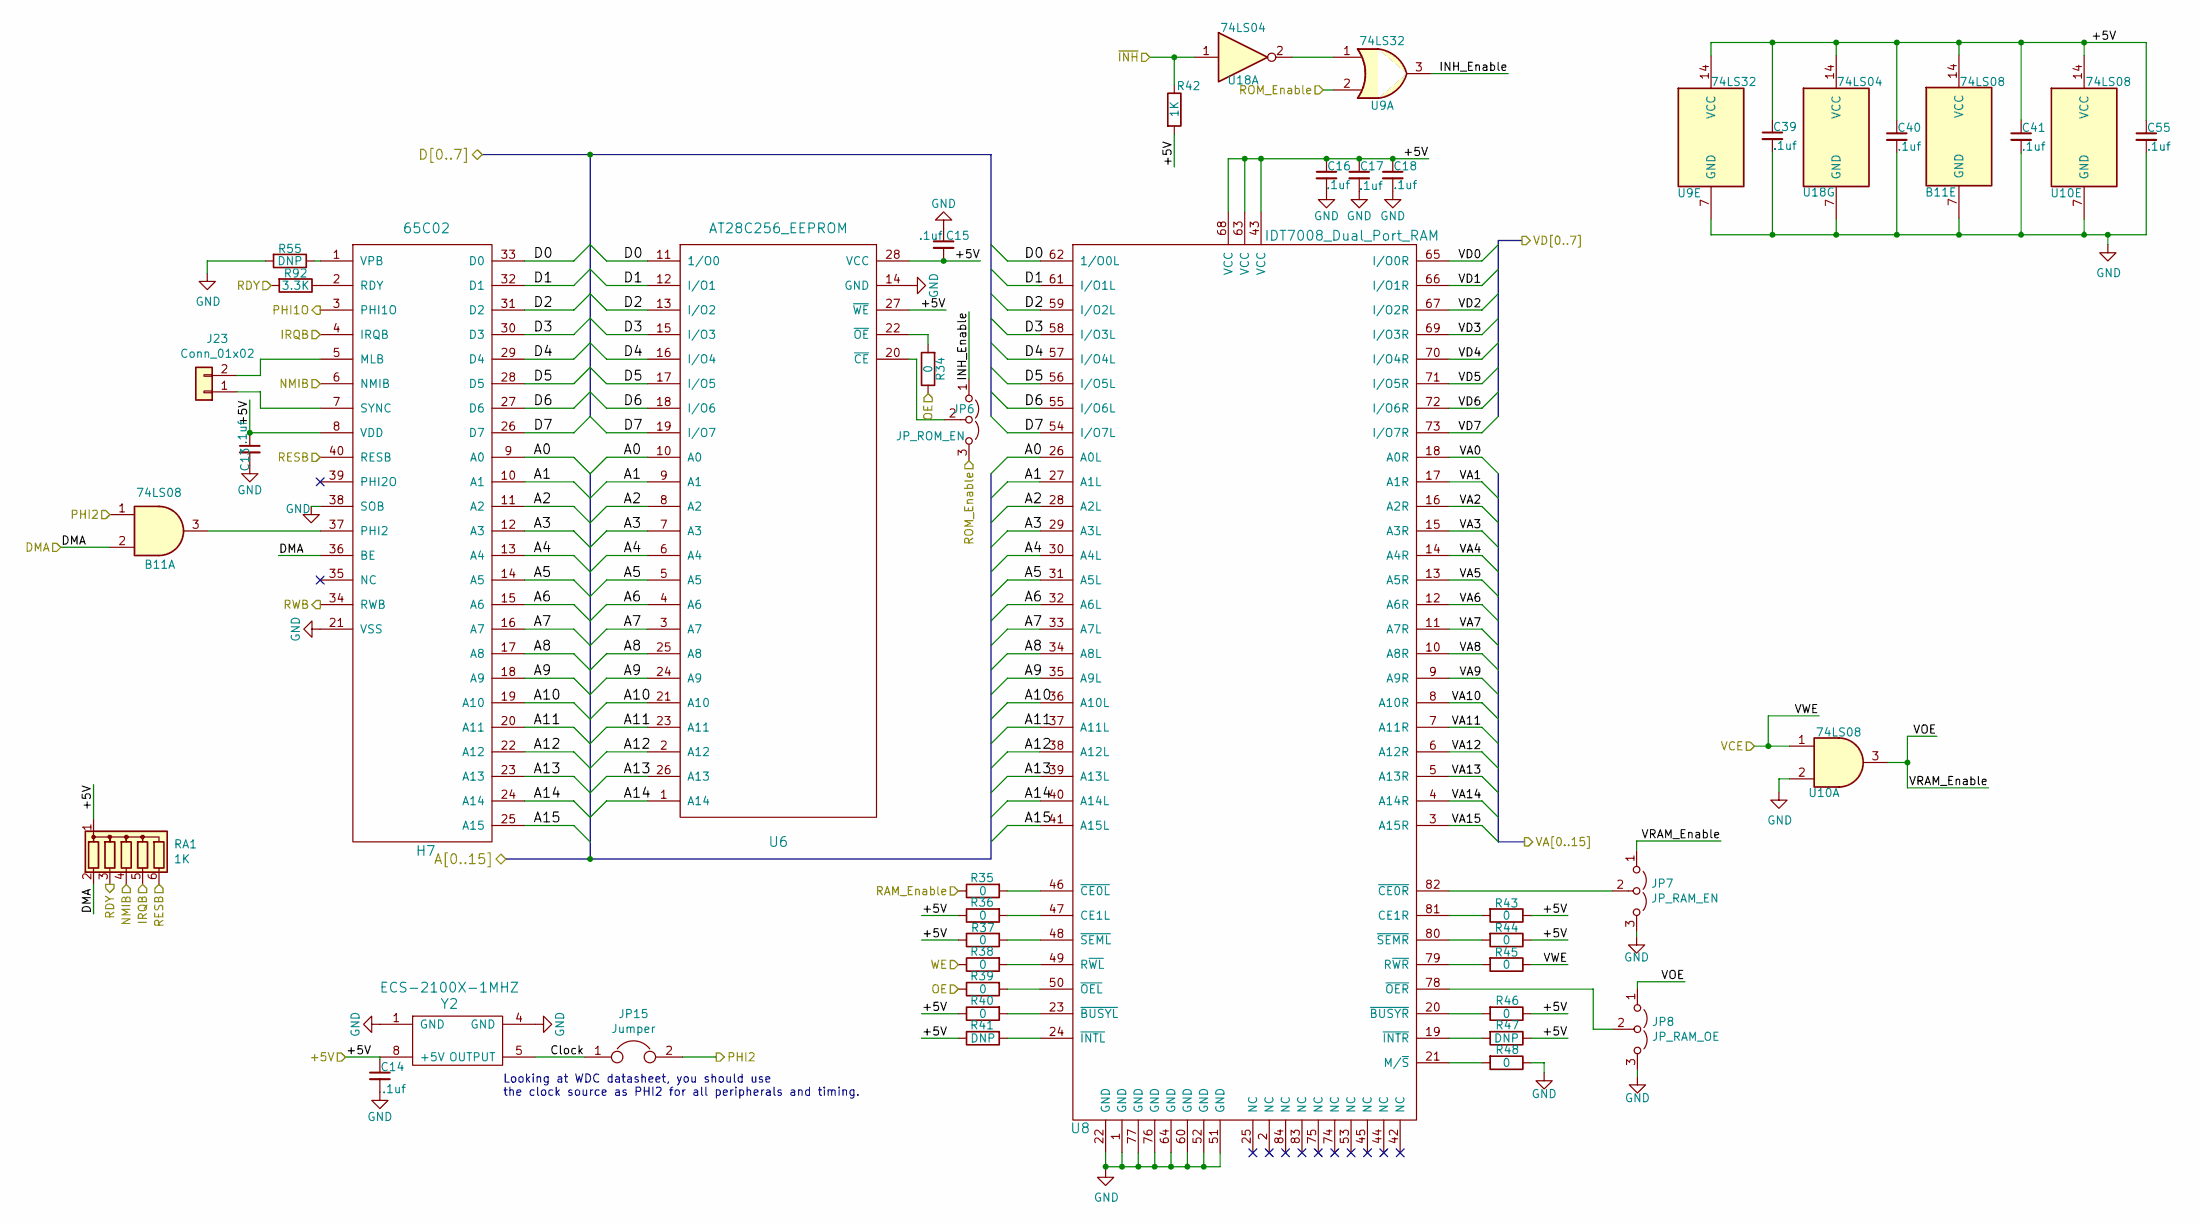
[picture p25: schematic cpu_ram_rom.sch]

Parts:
B11: 74LS08; DIP-14_W7.62mm_Socket_LongPads
C13, C14, C15, C16, C17, C18, C39, C40, C41, C55: .1uf; C_Disc_D3.0mm_W2.0mm_P2.50mm
H7: 65C02; DIP-40_W15.24mm_Socket_LongPads
J23: Conn_01x02; PinSocket_1x02_P2.54mm_Vertical
JP6: JP_ROM_EN; PinHeader_1x03_P2.54mm_Vertical
JP7: JP_RAM_EN; PinHeader_1x03_P2.54mm_Vertical
JP8: JP_RAM_OE; PinHeader_1x03_P2.54mm_Vertical
JP15: Jumper; PinHeader_1x02_P2.54mm_Vertical
R34, R35, R36, R37, R38, R39, R40, R43, R44, R45, R46, R48: 0; R_Axial_DIN0207_L6.3mm_D2.5mm_P10.16mm_Horizontal
R41, R47, R55: DNP; R_Axial_DIN0207_L6.3mm_D2.5mm_P10.16mm_Horizontal
R42: 1K; R_Axial_DIN0207_L6.3mm_D2.5mm_P10.16mm_Horizontal
R92: 3.3K; R_Axial_DIN0207_L6.3mm_D2.5mm_P10.16mm_Horizontal
RA1: 1K; R_Array_SIP6
U6: AT28C256_EEPROM; 28-526-11-SOCKET
U8: IDT7008_Dual_Port_RAM; Assman_PLCC84_ACCS084GT
U9: 74LS32; DIP-14_W7.62mm_Socket_LongPads
U10: 74LS08; DIP-14_W7.62mm_Socket_LongPads
U18: 74LS04; DIP-14_W7.62mm_Socket_LongPads
Y2: ECS-2100X-1MHZ; ECS-2100AX

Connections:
/Address_Decoding/+5V: B11.14 (VCC), C13.1, C14.1, C15.2, C16.1, C17.1, C18.1, C39.1, C40.1, C41.1, C55.1, H7.8 (VDD), R36.1, R37.1, R40.1, R41.1, R42.2, R43.1, R44.1, R46.1, R47.1, RA1.1 (common), U6.27 (~WE), U6.28 (VCC), U8.43 (VCC), U8.63 (VCC), U8.68 (VCC), U9.14 (VCC), U10.14 (VCC), U18.14 (VCC), Y2.8 (+5V); also elsewhere on the board
/Address_Decoding/A0: H7.9 (A0), U6.10 (A0), U8.26 (A0L); also elsewhere on the board
/Address_Decoding/A1: H7.10 (A1), U6.9 (A1), U8.27 (A1L); also elsewhere on the board
/Address_Decoding/A2: H7.11 (A2), U6.8 (A2), U8.28 (A2L); also elsewhere on the board
/Address_Decoding/A3: H7.12 (A3), U6.7 (A3), U8.29 (A3L); also elsewhere on the board
/Address_Decoding/A4: H7.13 (A4), U6.6 (A4), U8.30 (A4L); also elsewhere on the board
/Address_Decoding/A5: H7.14 (A5), U6.5 (A5), U8.31 (A5L); also elsewhere on the board
/Address_Decoding/A6: H7.15 (A6), U6.4 (A6), U8.32 (A6L); also elsewhere on the board
/Address_Decoding/A7: H7.16 (A7), U6.3 (A7), U8.33 (A7L); also elsewhere on the board
/Address_Decoding/A8: H7.17 (A8), U6.25 (A8), U8.34 (A8L); also elsewhere on the board
/Address_Decoding/A9: H7.18 (A9), U6.24 (A9), U8.35 (A9L); also elsewhere on the board
/Address_Decoding/A10: H7.19 (A10), U6.21 (A10), U8.36 (A10L); also elsewhere on the board
/Address_Decoding/A11: H7.20 (A11), U6.23 (A11), U8.37 (A11L); also elsewhere on the board
/Address_Decoding/A12: H7.22 (A12), U6.2 (A12), U8.38 (A12L); also elsewhere on the board
/Address_Decoding/A13: H7.23 (A13), U6.26 (A13), U8.39 (A13L); also elsewhere on the board
/Address_Decoding/A14: H7.24 (A14), U6.1 (A14), U8.40 (A14L); also elsewhere on the board
/Address_Decoding/A15: H7.25 (A15), U8.41 (A15L); also elsewhere on the board
/Address_Decoding/OE: R34.1, R39.1; also elsewhere on the board
/Address_Decoding/PHI2: B11.1, JP15.2; also elsewhere on the board
/Address_Decoding/RAM_Enable: R35.1; also elsewhere on the board
/Address_Decoding/ROM_Enable: JP6.3 (B), U9.2; also elsewhere on the board
/Address_Decoding/RW: H7.34 (RWB); also elsewhere on the board
/Address_Decoding/WE: R38.1; also elsewhere on the board
/CPU_RAM_ROM/Clock: JP15.1, Y2.5 (OUTPUT)
/CPU_RAM_ROM/D0: H7.33 (D0), U6.11 (1/O0), U8.62 (1/O0L); also elsewhere on the board
/CPU_RAM_ROM/D1: H7.32 (D1), U6.12 (I/O1), U8.61 (I/O1L); also elsewhere on the board
/CPU_RAM_ROM/D2: H7.31 (D2), U6.13 (I/O2), U8.59 (I/O2L); also elsewhere on the board
/CPU_RAM_ROM/D3: H7.30 (D3), U6.15 (I/O3), U8.58 (I/O3L); also elsewhere on the board
/CPU_RAM_ROM/D4: H7.29 (D4), U6.16 (I/O4), U8.57 (I/O4L); also elsewhere on the board
/CPU_RAM_ROM/D5: H7.28 (D5), U6.17 (I/O5), U8.56 (I/O5L); also elsewhere on the board
/CPU_RAM_ROM/D6: H7.27 (D6), U6.18 (I/O6), U8.55 (I/O6L); also elsewhere on the board
/CPU_RAM_ROM/DMA: B11.2, H7.36 (BE), RA1.2 (R1); also elsewhere on the board
/CPU_RAM_ROM/INH_Enable: JP6.1 (A), U9.3
/CPU_RAM_ROM/IRQB: H7.4 (IRQB), RA1.5 (R4); also elsewhere on the board
/CPU_RAM_ROM/NMIB: H7.6 (NMIB), RA1.4 (R3); also elsewhere on the board
/CPU_RAM_ROM/PHI1O: H7.3 (PHI1O); also elsewhere on the board
/CPU_RAM_ROM/RDY: R92.2, RA1.3 (R2); also elsewhere on the board
/CPU_RAM_ROM/RESB: H7.40 (RESB), RA1.6 (R5); also elsewhere on the board
/CPU_RAM_ROM/VA0: U8.18 (A0R); also elsewhere on the board
/CPU_RAM_ROM/VA1: U8.17 (A1R); also elsewhere on the board
/CPU_RAM_ROM/VA2: U8.16 (A2R); also elsewhere on the board
/CPU_RAM_ROM/VA3: U8.15 (A3R); also elsewhere on the board
/CPU_RAM_ROM/VA4: U8.14 (A4R); also elsewhere on the board
/CPU_RAM_ROM/VA5: U8.13 (A5R); also elsewhere on the board
/CPU_RAM_ROM/VA6: U8.12 (A6R); also elsewhere on the board
/CPU_RAM_ROM/VA7: U8.11 (A7R); also elsewhere on the board
/CPU_RAM_ROM/VA8: U8.10 (A8R); also elsewhere on the board
/CPU_RAM_ROM/VA9: U8.9 (A9R); also elsewhere on the board
/CPU_RAM_ROM/VA10: U8.8 (A10R); also elsewhere on the board
/CPU_RAM_ROM/VA11: U8.7 (A11R); also elsewhere on the board
/CPU_RAM_ROM/VA12: U8.6 (A12R); also elsewhere on the board
/CPU_RAM_ROM/VA13: U8.5 (A13R); also elsewhere on the board
/CPU_RAM_ROM/VA14: U8.4 (A14R); also elsewhere on the board
/CPU_RAM_ROM/VA15: U8.3 (A15R); also elsewhere on the board
/CPU_RAM_ROM/VCE: R45.1, U10.1; also elsewhere on the board
/CPU_RAM_ROM/VD0: U8.65 (I/O0R); also elsewhere on the board
/CPU_RAM_ROM/VD1: U8.66 (I/O1R); also elsewhere on the board
/CPU_RAM_ROM/VD2: U8.67 (I/O2R); also elsewhere on the board
/CPU_RAM_ROM/VD3: U8.69 (I/O3R); also elsewhere on the board
/CPU_RAM_ROM/VD4: U8.70 (I/O4R); also elsewhere on the board
/CPU_RAM_ROM/VD5: U8.71 (I/O5R); also elsewhere on the board
/CPU_RAM_ROM/VD6: U8.72 (I/O6R); also elsewhere on the board
/CPU_RAM_ROM/VD7: U8.73 (I/O7R); also elsewhere on the board
/CPU_RAM_ROM/VOE: JP7.1 (A), JP8.1 (A), U10.3
/CPU_RAM_ROM/~INH: R42.1, U18.1; also elsewhere on the board
GND: B11.7 (GND), C13.2, C14.2, C15.1, C16.2, C17.2, C18.2, C39.2, C40.2, C41.2, C55.2, H7.21 (VSS), H7.38 (SOB), JP7.3 (B), JP8.3 (B), R48.1, R55.2, U6.14 (GND), U8.1 (GND), U8.22 (GND), U8.51 (GND), U8.52 (GND), U8.60 (GND), U8.64 (GND), U8.76 (GND), U8.77 (GND), U9.7 (GND), U10.2, U10.7 (GND), U18.7 (GND), Y2.1 (GND), Y2.4 (GND); also elsewhere on the board
unnamed: B11.3, H7.37 (PHI2)
unnamed: H7.1 (VPB), R55.1
unnamed: H7.2 (RDY), R92.1
unnamed: H7.5 (MLB), J23.2
unnamed: H7.7 (SYNC), J23.1
unnamed: JP6.2 (C), U6.20 (~CE)
unnamed: JP7.2 (C), U8.82 (~CE0R)
unnamed: JP8.2 (C), U8.78 (~OER)
unnamed: R34.2, U6.22 (~OE)
unnamed: R35.2, U8.46 (~CE0L)
unnamed: R36.2, U8.47 (CE1L)
unnamed: R37.2, U8.48 (~SEML)
unnamed: R38.2, U8.49 (R~WL)
unnamed: R39.2, U8.50 (~OEL)
unnamed: R40.2, U8.23 (~BUSYL)
unnamed: R41.2, U8.24 (~INTL)
unnamed: R43.2, U8.81 (CE1R)
unnamed: R44.2, U8.80 (~SEMR)
unnamed: R45.2, U8.79 (R~WR)
unnamed: R46.2, U8.20 (~BUSYR)
unnamed: R47.2, U8.19 (~INTR)
unnamed: R48.2, U8.21 (M/~S)
unnamed: U9.1, U18.2

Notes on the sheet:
Looking at WDC datasheet, you should use the clock source as PHI2 for all peripherals and timing.

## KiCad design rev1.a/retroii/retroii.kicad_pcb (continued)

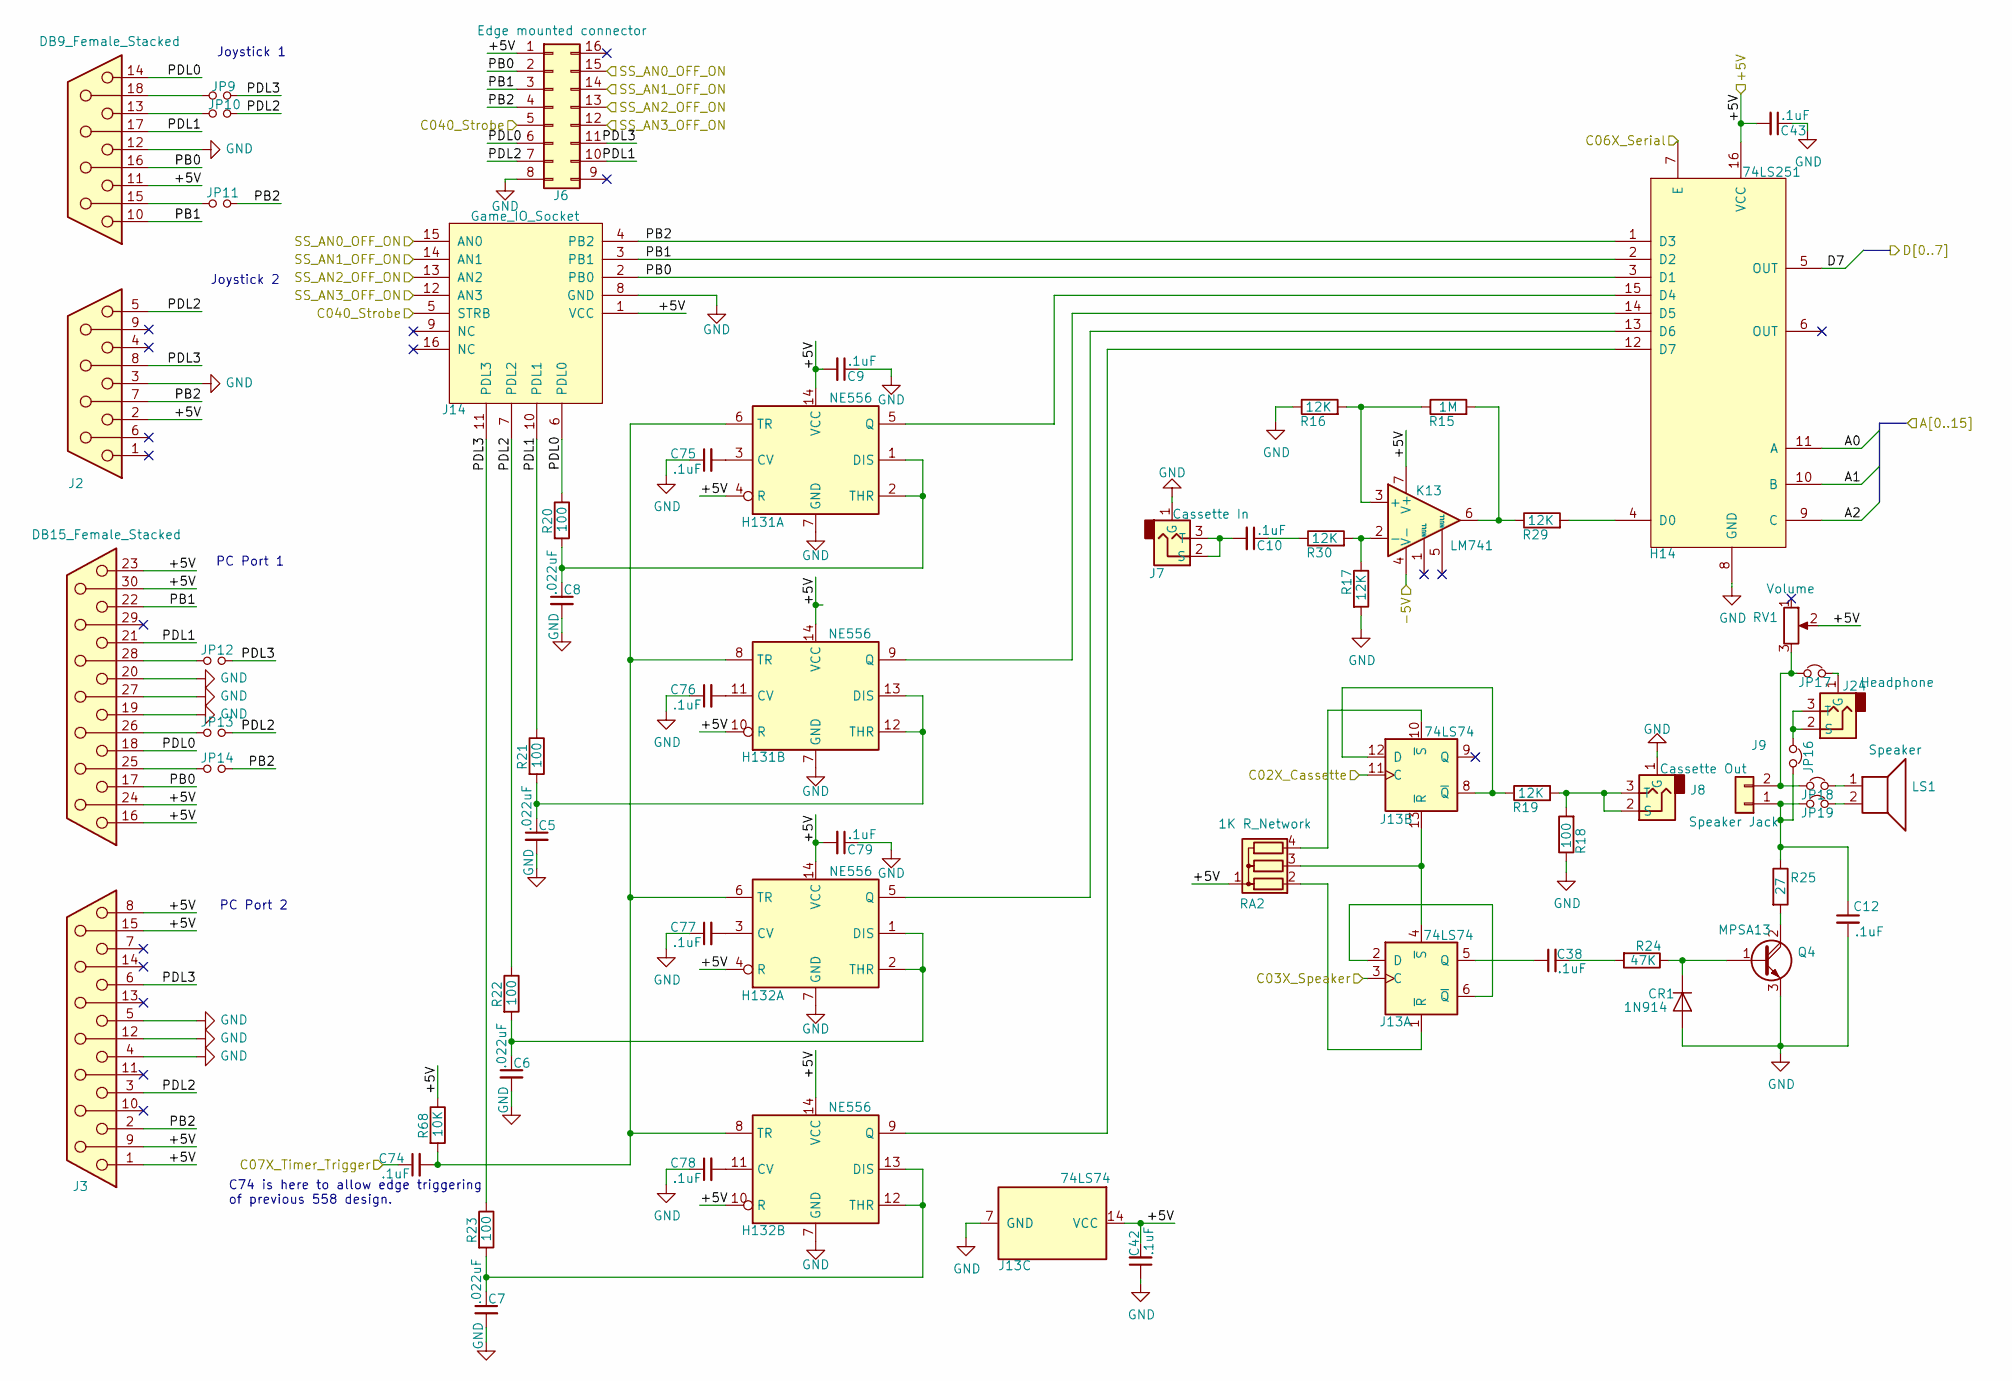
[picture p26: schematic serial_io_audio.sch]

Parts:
C5, C6, C7, C8: .022uF; C_Disc_D3.4mm_W2.1mm_P2.50mm
C9, C10, C12, C38, C42, C43, C74, C75, C76, C77, C78, C79: .1uF; C_Disc_D3.0mm_W2.0mm_P2.50mm
CR1: 1N914; D_DO-35_SOD27_P7.62mm_Horizontal
H14: 74LS251; DIP-16_W7.62mm_Socket_LongPads
H131, H132: NE556; DIP-14_W7.62mm_Socket_LongPads
J2: DB9_Female_Stacked; Amphenol_L17H2220131
J3: DB15_Female_Stacked; Amphenol_L17H2440131
J6: Edge mounted connector; PinSocket_2x08_P2.54mm_Vertical
J7: Cassette In; SJ13525NHeadphone
J8: Cassette Out; SJ13525NHeadphone
J9: Speaker Jack; PinSocket_1x02_P2.54mm_Vertical
J13: 74LS74; DIP-14_W7.62mm_Socket_LongPads
J14: Game_IO_Socket; DIP-16_W7.62mm_Socket_LongPads
J24: Headphone; SJ13525NHeadphone
JP9, JP10, JP11, JP12, JP13, JP14: Jumper_NO_Small; PinHeader_1x02_P2.54mm_Vertical
JP16, JP17, JP18, JP19: Jumper_NC_Small; PinHeader_1x02_P2.54mm_Vertical
K13: LM741; DIP-8_W7.62mm_Socket_LongPads
LS1: Speaker; CUI_CVI_1708
Q4: MPSA13; TO-92_Inline
R15: 1M; R_Axial_DIN0207_L6.3mm_D2.5mm_P10.16mm_Horizontal
R16, R17, R19, R29, R30: 12K; R_Axial_DIN0207_L6.3mm_D2.5mm_P10.16mm_Horizontal
R18, R20, R21, R22, R23: 100; R_Axial_DIN0207_L6.3mm_D2.5mm_P10.16mm_Horizontal
R24: 47K; R_Axial_DIN0207_L6.3mm_D2.5mm_P10.16mm_Horizontal
R25: 27; R_Axial_DIN0207_L6.3mm_D2.5mm_P10.16mm_Horizontal
R68: 10K; R_Axial_DIN0207_L6.3mm_D2.5mm_P10.16mm_Horizontal
RA2: 1K R_Network; R_Array_SIP4
RV1: Volume; BOURNS_91A1A-B24-D15L

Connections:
/Address_Decoding/+5V: C9.2, C42.2, C43.2, C79.2, H14.16 (VCC), H131.4 (R), H131.10 (R), H131.14 (VCC), H132.4 (R), H132.10 (R), H132.14 (VCC), J2.2, J2.11, J3.1, J3.8, J3.9, J3.15, J3.16, J3.23, J3.24, J3.30, J6.1, J13.14 (VCC), J14.1 (VCC), K13.7 (V+), R68.1, RA2.1 (common), RV1.2; also elsewhere on the board
/Address_Decoding/A0: H14.11 (A); also elsewhere on the board
/Address_Decoding/A1: H14.10 (B); also elsewhere on the board
/Address_Decoding/A2: H14.9 (C); also elsewhere on the board
/Address_Decoding/C02X_Cassette: J13.11 (C); also elsewhere on the board
/Address_Decoding/C03X_Speaker: J13.3 (C); also elsewhere on the board
/Address_Decoding/C06X_Serial: H14.7 (E); also elsewhere on the board
/Address_Decoding/C07X_Timer_Trigger: C74.1; also elsewhere on the board
/Address_Decoding/C040_Strobe: J6.5, J14.5 (STRB); also elsewhere on the board
/Address_Decoding/SS_AN0_OFF_ON: J6.15, J14.15 (AN0); also elsewhere on the board
/Address_Decoding/SS_AN1_OFF_ON: J6.14, J14.14 (AN1); also elsewhere on the board
/Address_Decoding/SS_AN2_OFF_ON: J6.13, J14.13 (AN2); also elsewhere on the board
/Address_Decoding/SS_AN3_OFF_ON: J6.12, J14.12 (AN3); also elsewhere on the board
/Peripheral_IO/-5V: K13.4 (V-); also elsewhere on the board
/Serial_IO_Audio/PB0: H14.3 (D1), J2.16, J3.17, J6.2, J14.2 (PB0)
/Serial_IO_Audio/PB1: H14.2 (D2), J2.10, J3.22, J6.3, J14.3 (PB1)
/Serial_IO_Audio/PB2: H14.1 (D3), J2.7, J3.2, J6.4, J14.4 (PB2), JP11.2, JP14.2
/Serial_IO_Audio/PDL0: J2.14, J3.18, J6.6, J14.6 (PDL0), R20.1
/Serial_IO_Audio/PDL1: J2.17, J3.21, J6.10, J14.10 (PDL1), R21.1
/Serial_IO_Audio/PDL2: J2.5, J3.3, J6.7, J14.7 (PDL2), JP10.2, JP13.2, R22.1
/Serial_IO_Audio/PDL3: J2.8, J3.6, J6.11, J14.11 (PDL3), JP9.2, JP12.2, R23.1
GND: C5.2, C6.2, C7.2, C8.2, C9.1, C12.2, C42.1, C43.1, C75.1, C76.1, C77.1, C78.1, C79.1, CR1.2 (A), H14.8 (GND), H131.7 (GND), H132.7 (GND), J2.3, J2.12, J3.4, J3.5, J3.12, J3.19, J3.20, J3.27, J6.8, J7.1 (G), J8.1 (G), J13.7 (GND), J14.8 (GND), Q4.3 (E), R16.1, R17.2, R18.1; also elsewhere on the board
unnamed: C5.1, H131.12 (THR), H131.13 (DIS), R21.2
unnamed: C6.1, H132.1 (DIS), H132.2 (THR), R22.2
unnamed: C7.1, H132.12 (THR), H132.13 (DIS), R23.2
unnamed: C8.1, H131.1 (DIS), H131.2 (THR), R20.2
unnamed: C10.1, R30.1
unnamed: C10.2, J7.2 (S), J7.3 (T)
unnamed: C12.1, J9.1, JP16.2, JP19.1, R25.1
unnamed: C38.1, J13.5 (Q)
unnamed: C38.2, R24.2
unnamed: C74.2, H131.6 (TR), H131.8 (TR), H132.6 (TR), H132.8 (TR), R68.2
unnamed: C75.2, H131.3 (CV)
unnamed: C76.2, H131.11 (CV)
unnamed: C77.2, H132.3 (CV)
unnamed: C78.2, H132.11 (CV)
unnamed: CR1.1 (K), Q4.1 (B), R24.1
unnamed: H14.4 (D0), R29.2
unnamed: H14.15 (D4), H131.5 (Q)
unnamed: H14.14 (D5), H131.9 (Q)
unnamed: H14.13 (D6), H132.5 (Q)
unnamed: H14.12 (D7), H132.9 (Q)
unnamed: J2.13, JP10.1
unnamed: J2.15, JP11.1
unnamed: J2.18, JP9.1
unnamed: J3.25, JP14.1
unnamed: J3.26, JP13.1
unnamed: J3.28, JP12.1
unnamed: J8.2 (S), J8.3 (T), R18.2, R19.2
unnamed: J9.2, JP17.1, JP18.1, RV1.3
unnamed: J13.1 (~R), RA2.2 (R1)
unnamed: J13.2 (D), J13.6 (~Q)
unnamed: J13.10 (~S), RA2.4 (R3)
unnamed: J13.8 (~Q), J13.12 (D), R19.1
unnamed: J13.4 (~S), J13.13 (~R), RA2.3 (R2)
unnamed: J24.1 (G), JP17.2
unnamed: J24.2 (S), J24.3 (T), JP16.1
unnamed: JP18.2, LS1.1
unnamed: JP19.2, LS1.2
unnamed: K13.2 (-), R17.1, R30.2
unnamed: K13.3 (+), R15.1, R16.2
unnamed: K13.6, R15.2, R29.1
unnamed: Q4.2 (C), R25.2

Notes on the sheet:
C74 is here to allow edge triggering of previous 558 design.
Joystick 1
Joystick 2
PC Port 1
PC Port 2

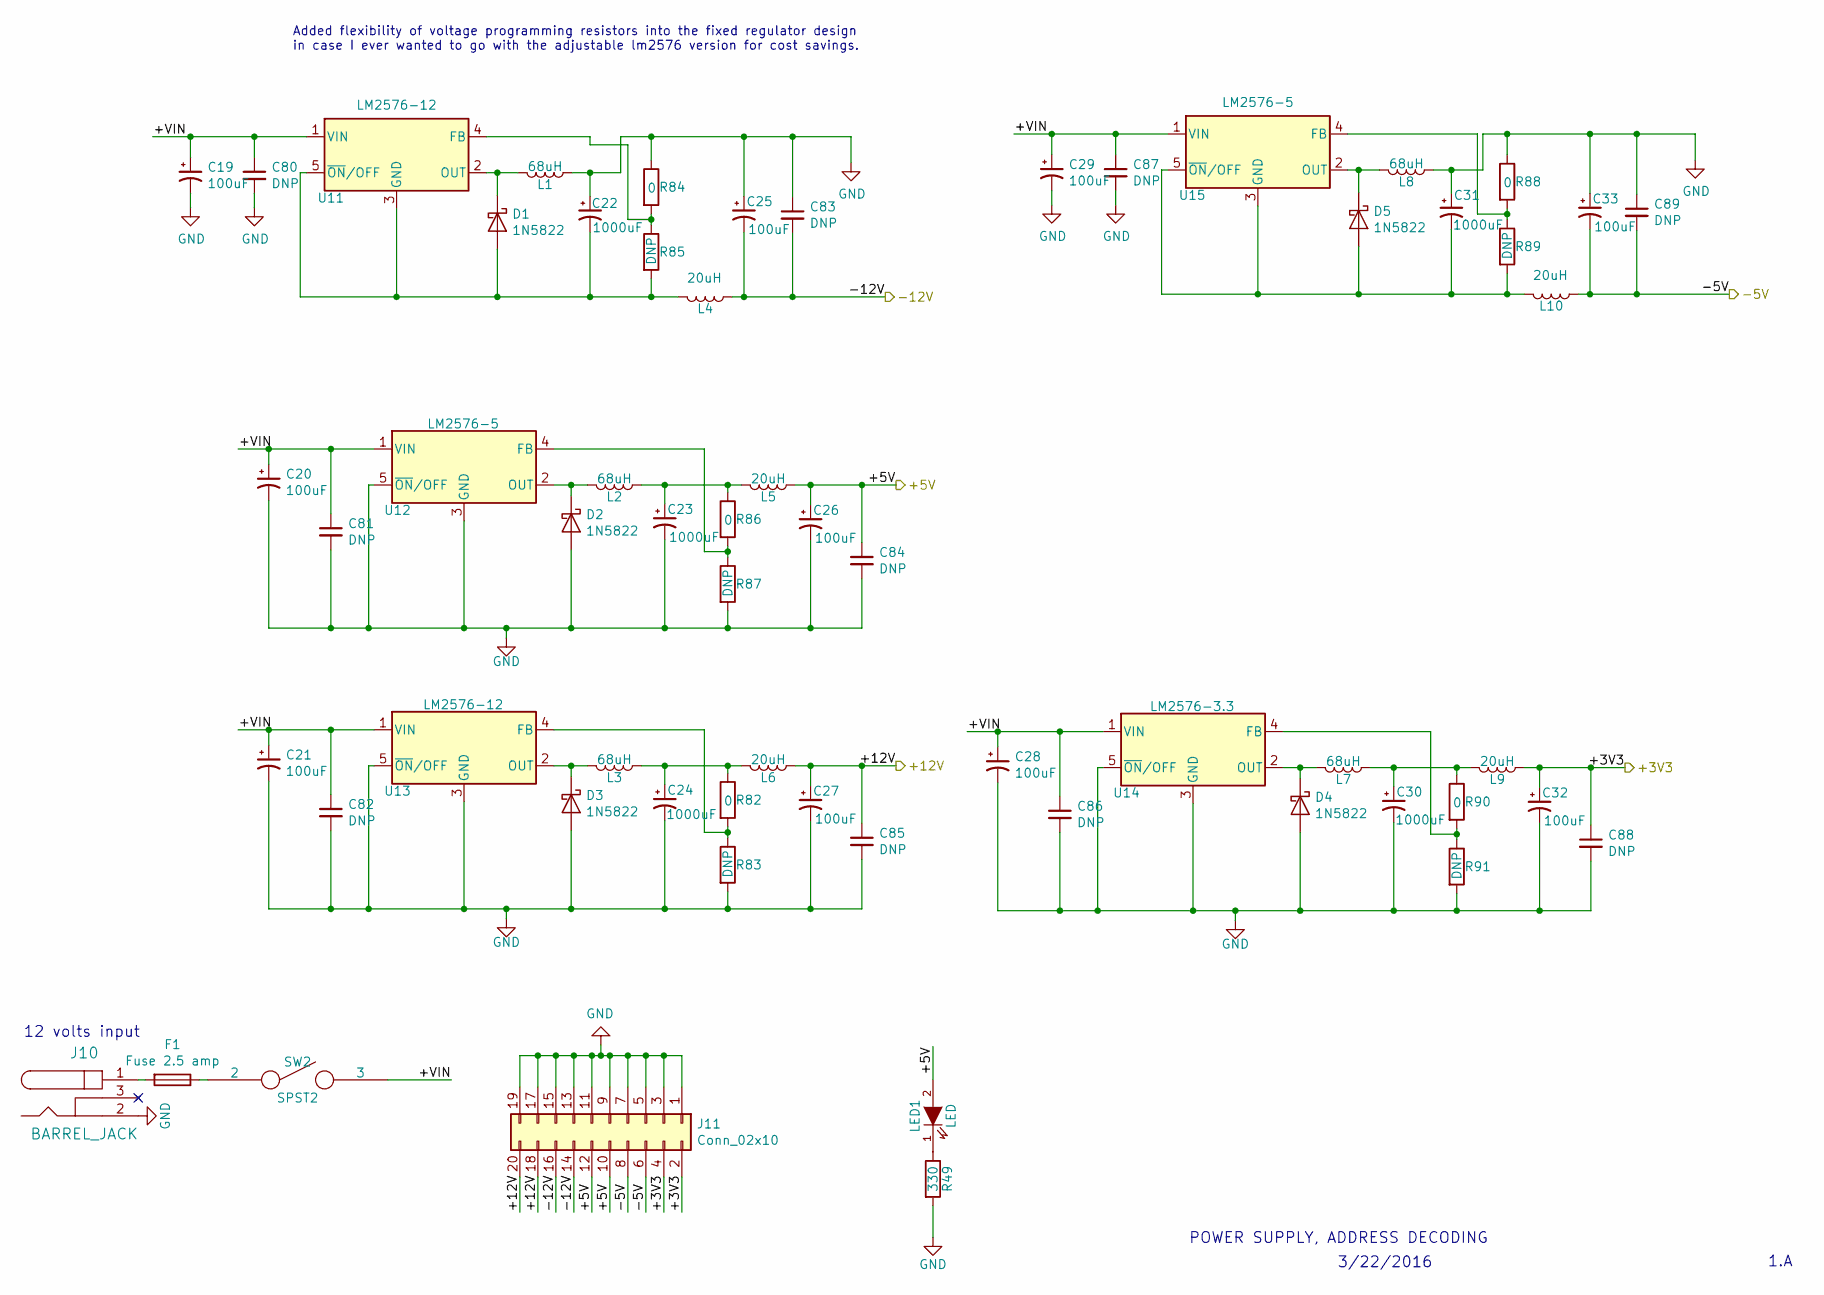
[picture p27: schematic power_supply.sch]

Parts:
C19, C20, C21, C25, C26, C27, C28, C29, C32, C33: 100uF; CP_Radial_D8.0mm_P3.50mm
C22, C23, C24, C30, C31: 1000uF; CP_Radial_D13.0mm_P5.00mm
C80, C81, C82, C83, C84, C85, C86, C87, C88, C89: DNP; C_Disc_D3.0mm_W2.0mm_P2.50mm
D1, D2, D3, D4, D5: 1N5822; D_DO-201AD_P15.24mm_Horizontal
F1: Fuse 2.5 amp; littlefuse_5.08_radial
J10: BARREL_JACK; Barrel_Jack_PJ002A
J11: Conn_02x10; PinSocket_2x10_P2.54mm_Vertical
L1, L2, L3, L7, L8: 68uH; Bourns_SRP1770TA-101M
L4, L5, L6, L9, L10: 20uH; Pulse_PF0382.223NLT
LED1: LED; WP1503CB_LED
R49: 330; R_Axial_DIN0207_L6.3mm_D2.5mm_P10.16mm_Horizontal
R82, R84, R86, R88, R90: 0; R_Axial_DIN0207_L6.3mm_D2.5mm_P10.16mm_Horizontal
R83, R85, R87, R89, R91: DNP; R_Axial_DIN0207_L6.3mm_D2.5mm_P10.16mm_Horizontal
SW2: SPST2; SW_Micro_Right_Angle_SPST
U11, U13: LM2576-12; TO-220-5_Horizontal_TabDown
U12, U15: LM2576-5; TO-220-5_Horizontal_TabDown
U14: LM2576-3.3; TO-220-5_Horizontal_TabDown

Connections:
/Address_Decoding/+5V: C26.1, C84.1, J11.10, J11.12, L5.1, LED1.2 (A); also elsewhere on the board
/Peripheral_IO/+12V: C27.1, C85.1, J11.18, J11.20, L6.1; also elsewhere on the board
/Peripheral_IO/-5V: C33.2, C89.2, J11.6, J11.8, L10.1; also elsewhere on the board
/Peripheral_IO/-12V: C25.2, C83.2, J11.14, J11.16, L4.1; also elsewhere on the board
/Power_Supply/+3V3: C32.1, C88.1, J11.2, J11.4, L9.1; also elsewhere on the board
/Power_Supply/+VIN: C19.1, C20.1, C21.1, C28.1, C29.1, C80.1, C81.1, C82.1, C86.1, C87.1, SW2.3, U11.1 (VIN), U12.1 (VIN), U13.1 (VIN), U14.1 (VIN), U15.1 (VIN)
GND: C19.2, C20.2, C21.2, C22.1, C23.2, C24.2, C25.1, C26.2, C27.2, C28.2, C29.2, C30.2, C31.1, C32.2, C33.1, C80.2, C81.2, C82.2, C83.1, C84.2, C85.2, C86.2, C87.2, C88.2, C89.1, D2.2 (A), D3.2 (A), D4.2 (A), J10.2, J11.1, J11.3, J11.5, J11.7, J11.9, J11.11, J11.13, J11.15, J11.17, J11.19, L1.1, L8.1, R49.2, R83.2, R84.1, R87.2, R88.1, R91.2, U12.3 (GND), U12.5 (~ON~/OFF), U13.3 (GND), U13.5 (~ON~/OFF), U14.3 (GND), U14.5 (~ON~/OFF); also elsewhere on the board
unnamed: C22.2, D1.2 (A), L4.2, R85.2, U11.3 (GND), U11.5 (~ON~/OFF)
unnamed: C23.1, L2.1, L5.2, R86.1
unnamed: C24.1, L3.1, L6.2, R82.1
unnamed: C30.1, L7.1, L9.2, R90.1
unnamed: C31.2, D5.2 (A), L10.2, R89.2, U15.3 (GND), U15.5 (~ON~/OFF)
unnamed: D1.1 (K), L1.2, U11.2 (OUT)
unnamed: D2.1 (K), L2.2, U12.2 (OUT)
unnamed: D3.1 (K), L3.2, U13.2 (OUT)
unnamed: D4.1 (K), L7.2, U14.2 (OUT)
unnamed: D5.1 (K), L8.2, U15.2 (OUT)
unnamed: F1.1, SW2.2
unnamed: F1.2, J10.1
unnamed: LED1.1 (K), R49.1
unnamed: R82.2, R83.1, U13.4 (FB)
unnamed: R84.2, R85.1, U11.4 (FB)
unnamed: R86.2, R87.1, U12.4 (FB)
unnamed: R88.2, R89.1, U15.4 (FB)
unnamed: R90.2, R91.1, U14.4 (FB)

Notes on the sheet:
12 volts input
POWER SUPPLY, ADDRESS DECODING
3/22/2016
1.A
Added flexibility of voltage programming resistors into the fixed regulator design in case I ever wanted to go with the adjustable lm2576 version for cost savings.

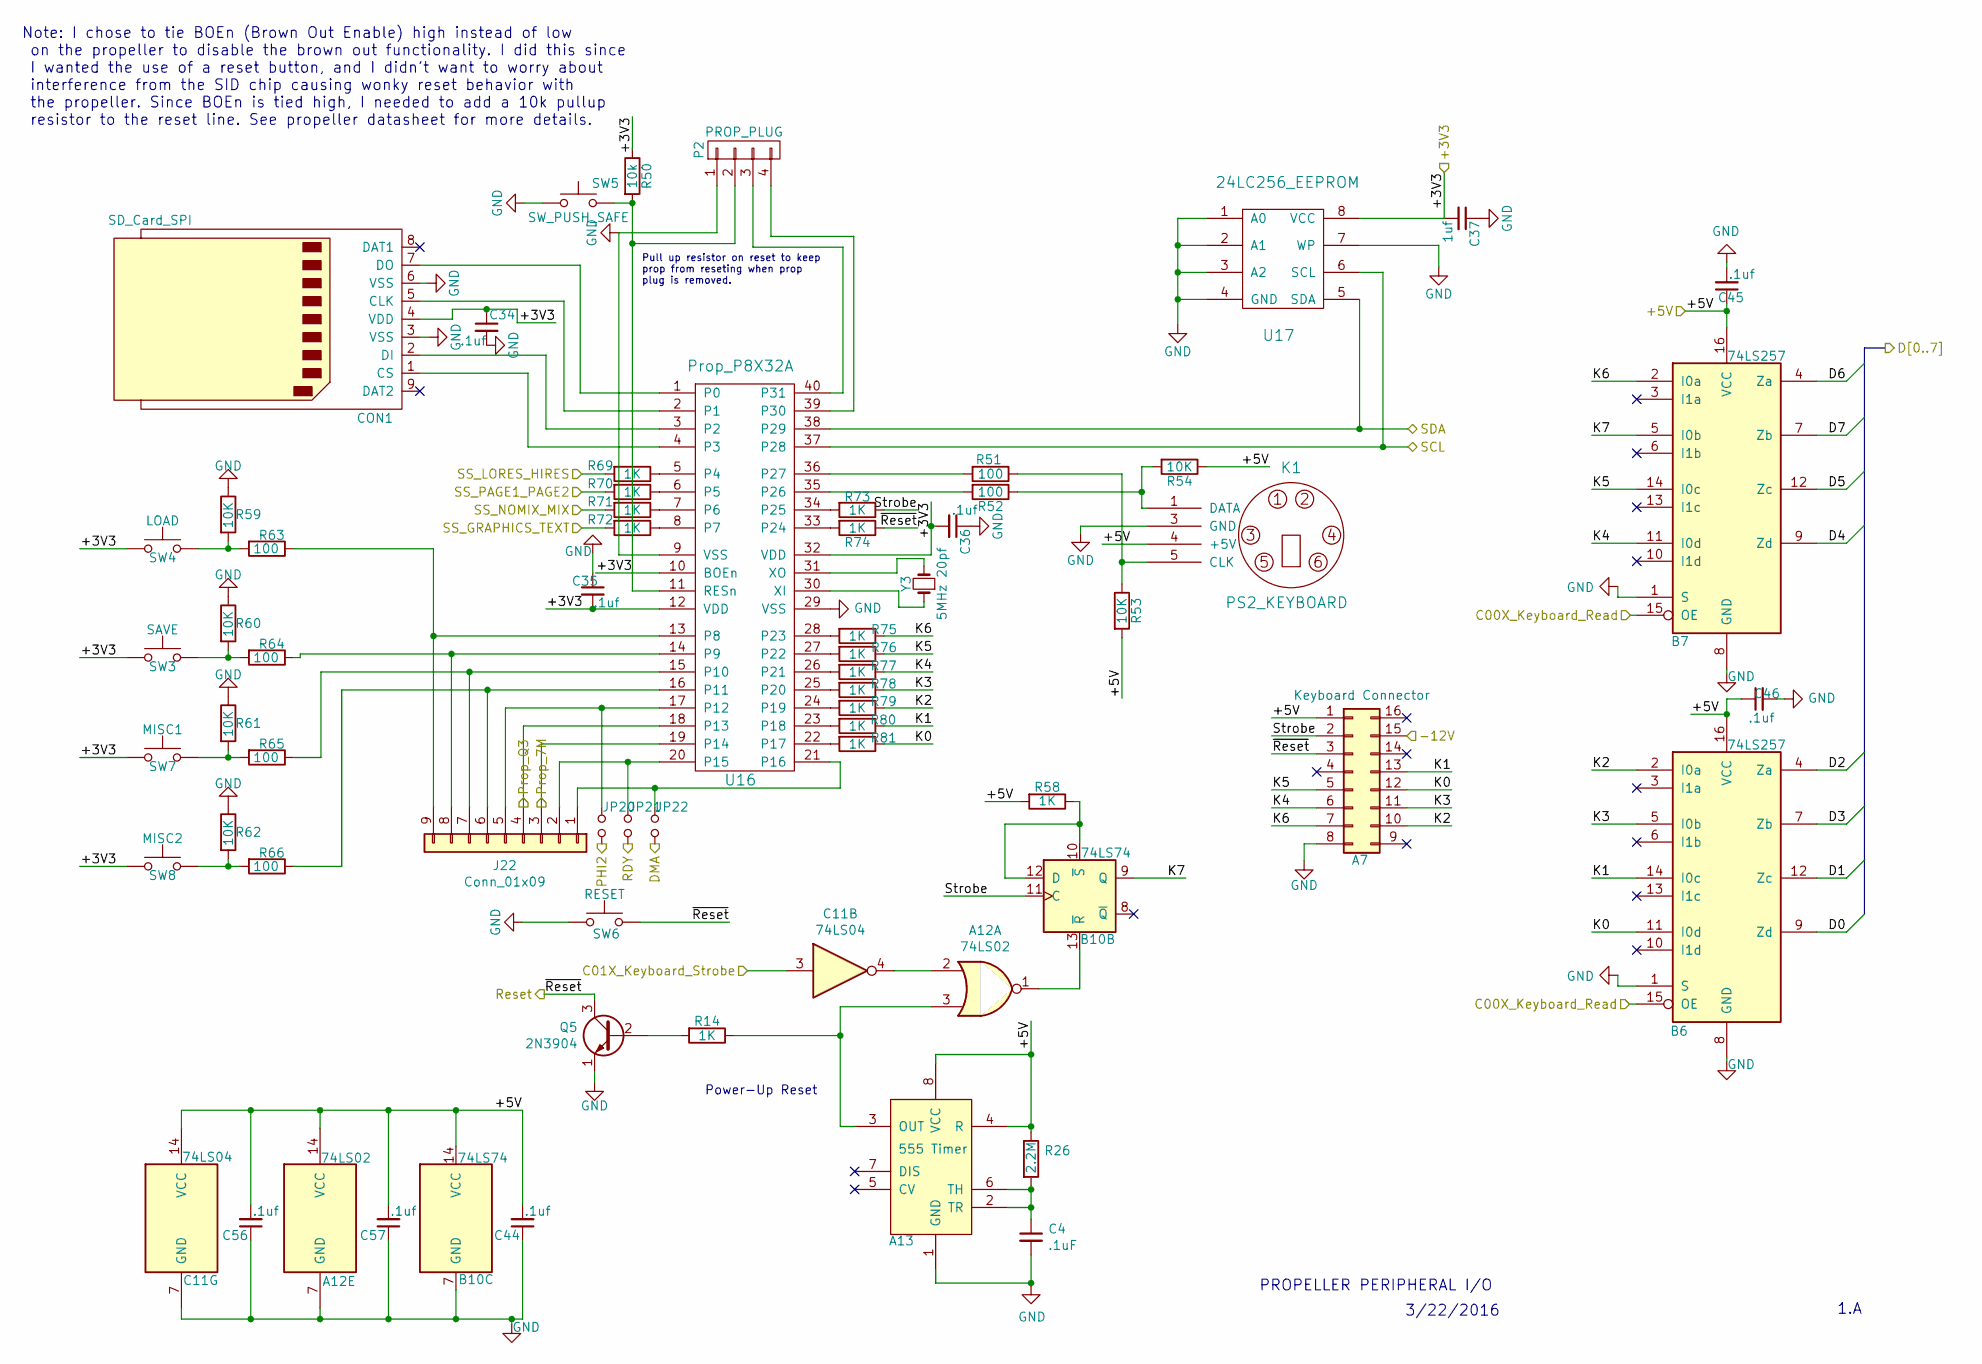
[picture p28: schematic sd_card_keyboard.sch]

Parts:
A7: Keyboard Connector; DIP-16_W7.62mm_Socket_LongPads
A12: 74LS02; DIP-14_W7.62mm_Socket_LongPads
A13: 555 Timer; DIP-8_W7.62mm_Socket_LongPads
B6, B7: 74LS257; DIP-16_W7.62mm_Socket_LongPads
B10: 74LS74; DIP-14_W7.62mm_Socket_LongPads
C4: .1uF; C_Disc_D3.0mm_W2.0mm_P2.50mm
C11: 74LS04; DIP-14_W7.62mm_Socket_LongPads
C34, C35, C36, C44, C45, C46, C56, C57: .1uf; C_Disc_D3.0mm_W2.0mm_P2.50mm
C37: 1uf; C_Disc_D4.7mm_W2.5mm_P5.00mm
CON1: SD_Card_SPI; DM1AASFPEJ_SDCARD
J22: Conn_01x09; PinSocket_1x09_P2.54mm_Vertical
JP20, JP21, JP22: Jumper_NO_Small; PinHeader_1x02_P2.54mm_Vertical
K1: PS2_KEYBOARD; MD60SM
P2: PROP_PLUG; PinHeader_1x04_P2.54mm_Vertical
Q5: 2N3904; TO-92_Inline
R14, R58, R69, R70, R71, R72, R73, R74, R75, R76, R77, R78, R79, R80, R81: 1K; R_Axial_DIN0207_L6.3mm_D2.5mm_P10.16mm_Horizontal
R26: 2.2M; R_Axial_DIN0207_L6.3mm_D2.5mm_P10.16mm_Horizontal
R50: 10k; R_Axial_DIN0207_L6.3mm_D2.5mm_P10.16mm_Horizontal
R51, R52, R63, R64, R65, R66: 100; R_Axial_DIN0207_L6.3mm_D2.5mm_P10.16mm_Horizontal
R53, R54, R59, R60, R61, R62: 10K; R_Axial_DIN0207_L6.3mm_D2.5mm_P10.16mm_Horizontal
SW3: SAVE; TE_Tactile_2-1825027-0
SW4: LOAD; TE_Tactile_2-1825027-0
SW5: SW_PUSH_SAFE; TE_1825910-6
SW6: RESET; TE_Tactile_2-1825027-0
SW7: MISC1; TE_Tactile_2-1825027-0
SW8: MISC2; TE_Tactile_2-1825027-0
U16: Prop_P8X32A; DIP-40_W15.24mm_Socket_LongPads
U17: 24LC256_EEPROM; DIP-8_W7.62mm_Socket_LongPads
Y3: 5MHz 20pf; crystal_hc-49s

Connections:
/Address_Decoding/+5V: A7.1, A12.14 (VCC), A13.4 (R), A13.8 (VCC), B6.16 (VCC), B7.16 (VCC), B10.14 (VCC), C11.14 (VCC), C44.2, C45.1, C46.1, C56.2, C57.2, K1.4 (+5V), R26.1, R53.2, R54.1, R58.2; also elsewhere on the board
/Address_Decoding/C00X_Keyboard_Read: B6.15 (OE), B7.15 (OE); also elsewhere on the board
/Address_Decoding/C01X_Keyboard_Strobe: C11.3; also elsewhere on the board
/Address_Decoding/PHI2: JP20.2; also elsewhere on the board
/Address_Decoding/SS_GRAPHICS_TEXT: R72.2; also elsewhere on the board
/Address_Decoding/SS_LORES_HIRES: R69.2; also elsewhere on the board
/Address_Decoding/SS_NOMIX_MIX: R71.2; also elsewhere on the board
/Address_Decoding/SS_PAGE1_PAGE2: R70.2; also elsewhere on the board
/CPU_RAM_ROM/D0: B6.9 (Zd); also elsewhere on the board
/CPU_RAM_ROM/D1: B6.12 (Zc); also elsewhere on the board
/CPU_RAM_ROM/D2: B6.4 (Za); also elsewhere on the board
/CPU_RAM_ROM/D3: B6.7 (Zb); also elsewhere on the board
/CPU_RAM_ROM/D4: B7.9 (Zd); also elsewhere on the board
/CPU_RAM_ROM/D5: B7.12 (Zc); also elsewhere on the board
/CPU_RAM_ROM/D6: B7.4 (Za); also elsewhere on the board
/CPU_RAM_ROM/DMA: JP22.2; also elsewhere on the board
/CPU_RAM_ROM/RDY: JP21.2; also elsewhere on the board
/CPU_RAM_ROM/RESB: A7.3, Q5.3 (C), R74.1, SW6.4; also elsewhere on the board
/Peripheral_IO/-12V: A7.15; also elsewhere on the board
/Peripheral_IO/Prop_7M: J22.3, U16.19 (P14); also elsewhere on the board
/Peripheral_IO/Prop_Q3: J22.4, U16.18 (P13); also elsewhere on the board
/Power_Supply/+3V3: C34.1, C35.2, C36.2, C37.2, CON1.4 (VDD), R50.1, SW3.1, SW4.1, SW7.1, SW8.1, U16.10 (BOEn), U16.12 (VDD), U16.32 (VDD), U17.8 (VCC); also elsewhere on the board
/SD_Card_And_Keyboard/K0: A7.12, B6.11 (I0d), R81.1
/SD_Card_And_Keyboard/K1: A7.13, B6.14 (I0c), R80.1
/SD_Card_And_Keyboard/K2: A7.10, B6.2 (I0a), R79.1
/SD_Card_And_Keyboard/K3: A7.11, B6.5 (I0b), R78.1
/SD_Card_And_Keyboard/K4: A7.6, B7.11 (I0d), R77.1
/SD_Card_And_Keyboard/K5: A7.5, B7.14 (I0c), R76.1
/SD_Card_And_Keyboard/K6: A7.7, B7.2 (I0a), R75.1
/SD_Card_And_Keyboard/K7: B7.5 (I0b), B10.9 (Q)
/SD_Card_And_Keyboard/SCL: U16.37 (P28), U17.6 (SCL); also elsewhere on the board
/SD_Card_And_Keyboard/SDA: U16.38 (P29), U17.5 (SDA); also elsewhere on the board
/SD_Card_And_Keyboard/Strobe: A7.2, B10.11 (C), R73.1
GND: A7.8, A12.7 (GND), A13.1 (GND), B6.1 (S), B6.8 (GND), B7.1 (S), B7.8 (GND), B10.7 (GND), C4.2, C11.7 (GND), C34.2, C35.1, C36.1, C37.1, C44.1, C45.2, C46.2, C56.1, C57.1, CON1.3 (VSS), CON1.6 (VSS), K1.3 (GND), P2.1, Q5.1 (E), R59.1, R60.1, R61.1, R62.1, SW5.1, SW6.1, U16.9 (VSS), U16.29 (VSS), U17.1 (A0), U17.2 (A1), U17.3 (A2), U17.4 (GND), U17.7 (WP); also elsewhere on the board
unnamed: A12.1, B10.13 (~R)
unnamed: A12.2, C11.4
unnamed: A12.3, A13.3 (OUT), R14.1
unnamed: A13.2 (TR), A13.6 (TH), C4.1, R26.2
unnamed: B10.10 (~S), B10.12 (D), R58.1
unnamed: CON1.1 (CS), U16.4 (P3)
unnamed: CON1.2 (DI), U16.3 (P2)
unnamed: CON1.5 (CLK), U16.2 (P1)
unnamed: CON1.7 (DO), U16.1 (P0)
unnamed: J22.1, JP22.1, U16.21 (P16)
unnamed: J22.2, JP21.1, U16.20 (P15)
unnamed: J22.5, JP20.1, U16.17 (P12)
unnamed: J22.6, R66.1, U16.16 (P11)
unnamed: J22.7, R65.1, U16.15 (P10)
unnamed: J22.8, R64.1, U16.14 (P9)
unnamed: J22.9, R63.1, U16.13 (P8)
unnamed: K1.1 (DATA), R52.1, R54.2
unnamed: K1.5 (CLK), R51.1, R53.1
unnamed: P2.2, R50.2, SW5.4, U16.11 (RESn)
unnamed: P2.3, U16.40 (P31)
unnamed: P2.4, U16.39 (P30)
unnamed: Q5.2 (B), R14.2
unnamed: R51.2, U16.36 (P27)
unnamed: R52.2, U16.35 (P26)
unnamed: R59.2, R63.2, SW4.4
unnamed: R60.2, R64.2, SW3.4
unnamed: R61.2, R65.2, SW7.4
unnamed: R62.2, R66.2, SW8.4
unnamed: R69.1, U16.5 (P4)
unnamed: R70.1, U16.6 (P5)
unnamed: R71.1, U16.7 (P6)
unnamed: R72.1, U16.8 (P7)
unnamed: R73.2, U16.34 (P25)
unnamed: R74.2, U16.33 (P24)
unnamed: R75.2, U16.28 (P23)
unnamed: R76.2, U16.27 (P22)
unnamed: R77.2, U16.26 (P21)
unnamed: R78.2, U16.25 (P20)
unnamed: R79.2, U16.24 (P19)
unnamed: R80.2, U16.23 (P18)
unnamed: R81.2, U16.22 (P17)
unnamed: U16.30 (XI), Y3.1
unnamed: U16.31 (XO), Y3.2

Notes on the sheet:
Note: I chose to tie BOEn (Brown Out Enable) high instead of low on the propeller to disable the brown out functionality. I did this since I wanted the use of a reset button, and I didn't want to worry about interference from the SID chip causing wonky reset behavior with the propeller. Since BOEn 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
Pull up resistor on reset to keep prop from reseting when prop plug is removed.
PROPELLER PERIPHERAL I/O
3/22/2016
1.A
Power-Up Reset

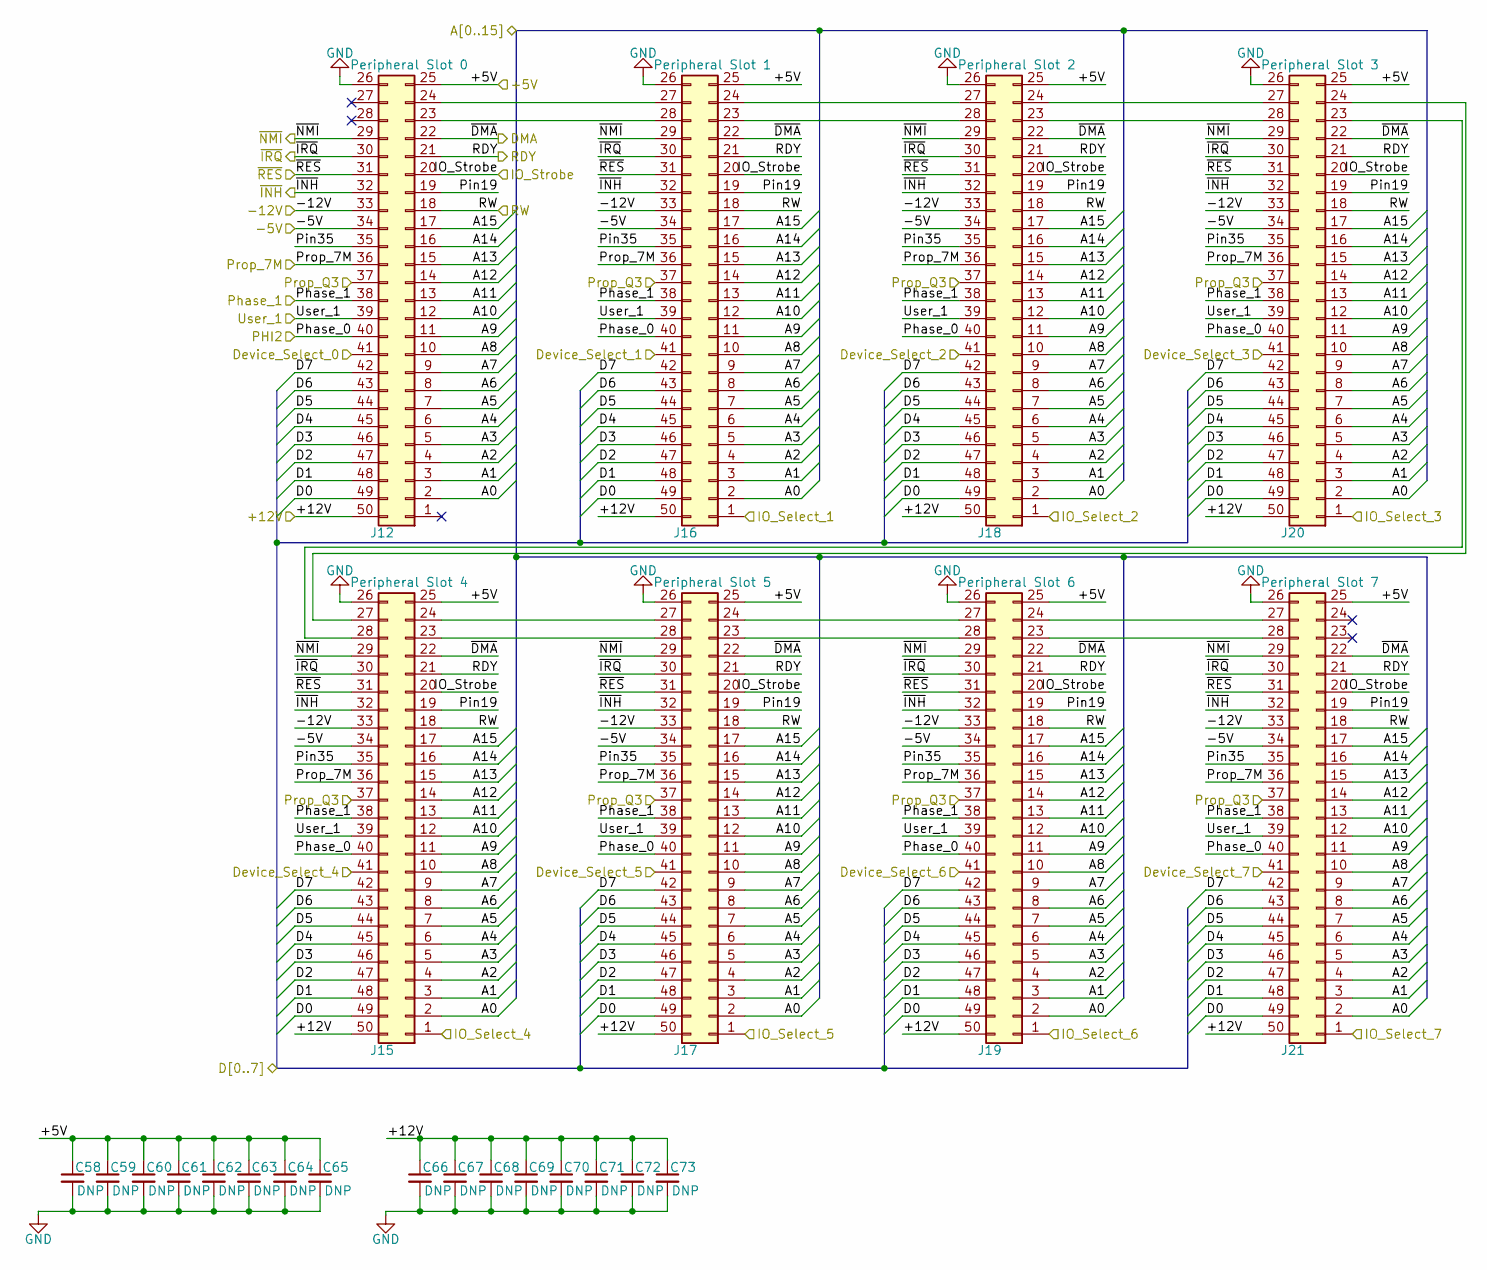
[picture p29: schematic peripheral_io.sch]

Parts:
C58, C59, C60, C61, C62, C63, C64, C65, C66, C67, C68, C69, C70, C71, C72, C73: DNP; C_Disc_D3.0mm_W2.0mm_P2.50mm
J12: Peripheral Slot 0; TE_5530841-5
J15: Peripheral Slot 4; TE_5530841-5
J16: Peripheral Slot 1; TE_5530841-5
J17: Peripheral Slot 5; TE_5530841-5
J18: Peripheral Slot 2; TE_5530841-5
J19: Peripheral Slot 6; TE_5530841-5
J20: Peripheral Slot 3; TE_5530841-5
J21: Peripheral Slot 7; TE_5530841-5

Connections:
/Address_Decoding/+5V: C58.1, C59.1, C60.1, C61.1, C62.1, C63.1, C64.1, C65.1, J12.25, J15.25, J16.25, J17.25, J18.25, J19.25, J20.25, J21.25; also elsewhere on the board
/Address_Decoding/A0: J12.2, J15.2, J16.2, J17.2, J18.2, J19.2, J20.2, J21.2; also elsewhere on the board
/Address_Decoding/A1: J12.3, J15.3, J16.3, J17.3, J18.3, J19.3, J20.3, J21.3; also elsewhere on the board
/Address_Decoding/A2: J12.4, J15.4, J16.4, J17.4, J18.4, J19.4, J20.4, J21.4; also elsewhere on the board
/Address_Decoding/A3: J12.5, J15.5, J16.5, J17.5, J18.5, J19.5, J20.5, J21.5; also elsewhere on the board
/Address_Decoding/A4: J12.6, J15.6, J16.6, J17.6, J18.6, J19.6, J20.6, J21.6; also elsewhere on the board
/Address_Decoding/A5: J12.7, J15.7, J16.7, J17.7, J18.7, J19.7, J20.7, J21.7; also elsewhere on the board
/Address_Decoding/A6: J12.8, J15.8, J16.8, J17.8, J18.8, J19.8, J20.8, J21.8; also elsewhere on the board
/Address_Decoding/A8: J12.10, J15.10, J16.10, J17.10, J18.10, J19.10, J20.10, J21.10; also elsewhere on the board
/Address_Decoding/A9: J12.11, J15.11, J16.11, J17.11, J18.11, J19.11, J20.11, J21.11; also elsewhere on the board
/Address_Decoding/A10: J12.12, J15.12, J16.12, J17.12, J18.12, J19.12, J20.12, J21.12; also elsewhere on the board
/Address_Decoding/A11: J12.13, J15.13, J16.13, J17.13, J18.13, J19.13, J20.13, J21.13; also elsewhere on the board
/Address_Decoding/A12: J12.14, J15.14, J16.14, J17.14, J18.14, J19.14, J20.14, J21.14; also elsewhere on the board
/Address_Decoding/A13: J12.15, J15.15, J16.15, J17.15, J18.15, J19.15, J20.15, J21.15; also elsewhere on the board
/Address_Decoding/A14: J12.16, J15.16, J16.16, J17.16, J18.16, J19.16, J20.16, J21.16; also elsewhere on the board
/Address_Decoding/A15: J12.17, J15.17, J16.17, J17.17, J18.17, J19.17, J20.17, J21.17; also elsewhere on the board
/Address_Decoding/C0AX_Device_Select_2: J18.41; also elsewhere on the board
/Address_Decoding/C0BX_Device_Select_3: J20.41; also elsewhere on the board
/Address_Decoding/C0CX_Device_Select_4: J15.41; also elsewhere on the board
/Address_Decoding/C0DX_Device_Select_5: J17.41; also elsewhere on the board
/Address_Decoding/C0EX_Device_Select_6: J19.41; also elsewhere on the board
/Address_Decoding/C0FX_Device_Select_7: J21.41; also elsewhere on the board
/Address_Decoding/C1XX_IO_1: J16.1; also elsewhere on the board
/Address_Decoding/C2XX_IO_2: J18.1; also elsewhere on the board
/Address_Decoding/C3XX_IO_3: J20.1; also elsewhere on the board
/Address_Decoding/C4XX_IO_4: J15.1; also elsewhere on the board
/Address_Decoding/C5XX_IO_5: J17.1; also elsewhere on the board
/Address_Decoding/C6XX_IO_6: J19.1; also elsewhere on the board
/Address_Decoding/C7XX_IO_7: J21.1; also elsewhere on the board
/Address_Decoding/C08X_Device_Select_0: J12.41; also elsewhere on the board
/Address_Decoding/C09X_Device_Select_1: J16.41; also elsewhere on the board
/Address_Decoding/IO_Strobe: J12.20, J15.20, J16.20, J17.20, J18.20, J19.20, J20.20, J21.20; also elsewhere on the board
/Address_Decoding/PHI2: J12.40, J15.40, J16.40, J17.40, J18.40, J19.40, J20.40, J21.40; also elsewhere on the board
/Address_Decoding/RW: J12.18, J15.18, J16.18, J17.18, J18.18, J19.18, J20.18, J21.18; also elsewhere on the board
/Address_Decoding/User_1: J12.39, J15.39, J16.39, J17.39, J18.39, J19.39, J20.39, J21.39; also elsewhere on the board
/CPU_RAM_ROM/D0: J12.49, J15.49, J16.49, J17.49, J18.49, J19.49, J20.49, J21.49; also elsewhere on the board
/CPU_RAM_ROM/D1: J12.48, J15.48, J16.48, J17.48, J18.48, J19.48, J20.48, J21.48; also elsewhere on the board
/CPU_RAM_ROM/D2: J12.47, J15.47, J16.47, J17.47, J18.47, J19.47, J20.47, J21.47; also elsewhere on the board
/CPU_RAM_ROM/D3: J12.46, J15.46, J16.46, J17.46, J18.46, J19.46, J20.46, J21.46; also elsewhere on the board
/CPU_RAM_ROM/D4: J12.45, J15.45, J16.45, J17.45, J18.45, J19.45, J20.45, J21.45; also elsewhere on the board
/CPU_RAM_ROM/D5: J12.44, J15.44, J16.44, J17.44, J18.44, J19.44, J20.44, J21.44; also elsewhere on the board
/CPU_RAM_ROM/D6: J12.43, J15.43, J16.43, J17.43, J18.43, J19.43, J20.43, J21.43; also elsewhere on the board
/CPU_RAM_ROM/DMA: J12.22, J15.22, J16.22, J17.22, J18.22, J19.22, J20.22, J21.22; also elsewhere on the board
/CPU_RAM_ROM/IRQB: J12.30, J15.30, J16.30, J17.30, J18.30, J19.30, J20.30, J21.30; also elsewhere on the board
/CPU_RAM_ROM/NMIB: J12.29, J15.29, J16.29, J17.29, J18.29, J19.29, J20.29, J21.29; also elsewhere on the board
/CPU_RAM_ROM/PHI1O: J12.38, J15.38, J16.38, J17.38, J18.38, J19.38, J20.38, J21.38; also elsewhere on the board
/CPU_RAM_ROM/RDY: J12.21, J15.21, J16.21, J17.21, J18.21, J19.21, J20.21, J21.21; also elsewhere on the board
/CPU_RAM_ROM/RESB: J12.31, J15.31, J16.31, J17.31, J18.31, J19.31, J20.31, J21.31; also elsewhere on the board
/CPU_RAM_ROM/~INH: J12.32, J15.32, J16.32, J17.32, J18.32, J19.32, J20.32, J21.32; also elsewhere on the board
/Peripheral_IO/+12V: C66.1, C67.1, C68.1, C69.1, C70.1, C71.1, C72.1, C73.1, J12.50, J15.50, J16.50, J17.50, J18.50, J19.50, J20.50, J21.50; also elsewhere on the board
/Peripheral_IO/-5V: J12.34, J15.34, J16.34, J17.34, J18.34, J19.34, J20.34, J21.34; also elsewhere on the board
/Peripheral_IO/-12V: J12.33, J15.33, J16.33, J17.33, J18.33, J19.33, J20.33, J21.33; also elsewhere on the board
/Peripheral_IO/Pin19: J12.19, J15.19, J16.19, J17.19, J18.19, J19.19, J20.19, J21.19
/Peripheral_IO/Pin35: J12.35, J15.35, J16.35, J17.35, J18.35, J19.35, J20.35, J21.35
/Peripheral_IO/Prop_7M: J12.36, J15.36, J16.36, J17.36, J18.36, J19.36, J20.36, J21.36; also elsewhere on the board
/Peripheral_IO/Prop_Q3: J12.37, J15.37, J16.37, J17.37, J18.37, J19.37, J20.37, J21.37; also elsewhere on the board
GND: C58.2, C59.2, C60.2, C61.2, C62.2, C63.2, C64.2, C65.2, C66.2, C67.2, C68.2, C69.2, C70.2, C71.2, C72.2, C73.2, J12.26, J15.26, J16.26, J17.26, J18.26, J19.26, J20.26, J21.26; also elsewhere on the board
unnamed: J12.23, J16.28
unnamed: J12.24, J16.27
unnamed: J15.23, J17.28
unnamed: J15.24, J17.27
unnamed: J15.27, J20.24
unnamed: J15.28, J20.23
unnamed: J16.23, J18.28
unnamed: J16.24, J18.27
unnamed: J17.23, J19.28
unnamed: J17.24, J19.27
unnamed: J18.23, J20.28
unnamed: J18.24, J20.27
unnamed: J19.23, J21.28
unnamed: J19.24, J21.27

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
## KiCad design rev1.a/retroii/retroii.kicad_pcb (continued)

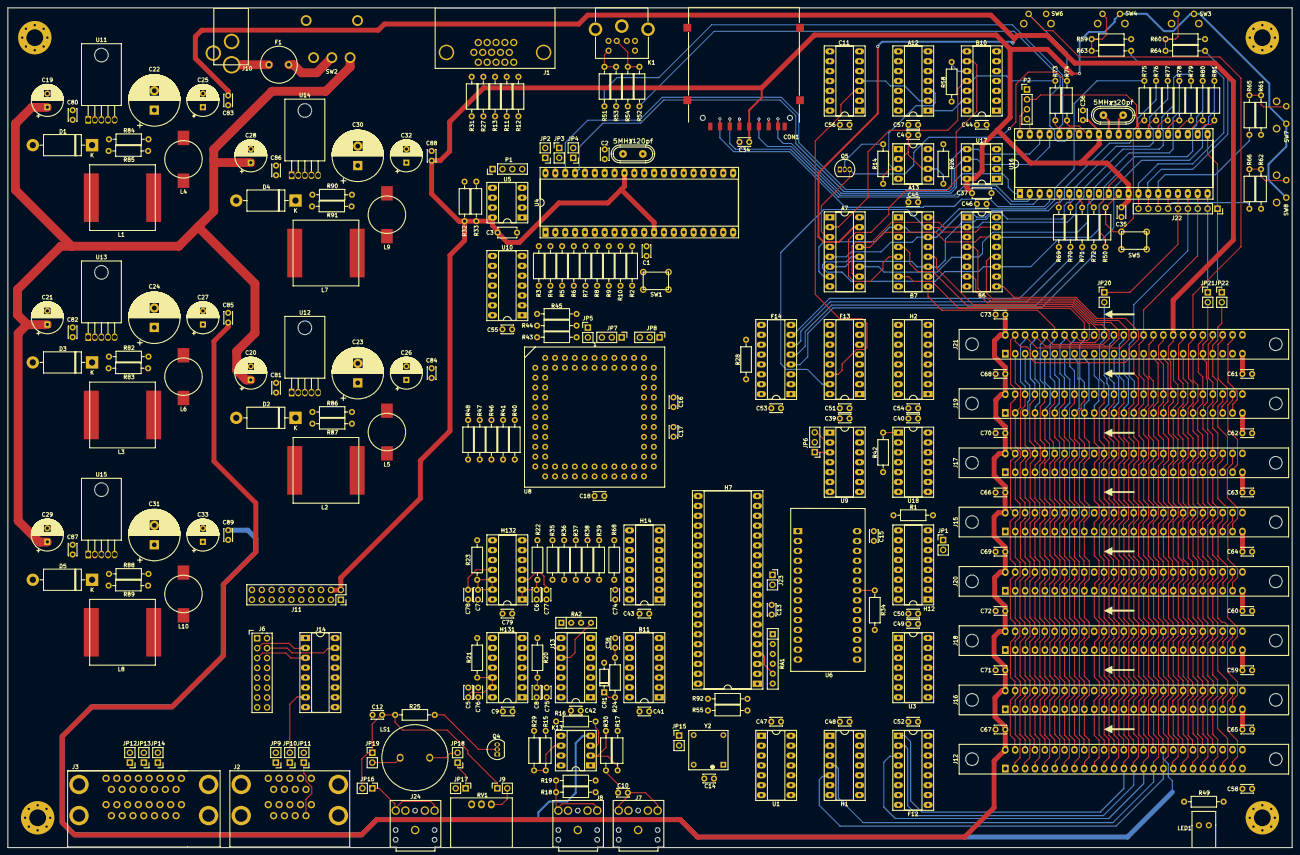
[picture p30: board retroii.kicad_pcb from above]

Board: 4 copper layers, 330.2 x 215.9 mm, 299 parts (0 on the bottom side), 305 nets.

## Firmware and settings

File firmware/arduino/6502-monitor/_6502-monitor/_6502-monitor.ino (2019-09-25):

const char ADDR[] = {53, 51, 49, 47, 45, 43, 41, 39, 37, 35, 33, 31, 29, 27, 25, 23};
const char DATA[] = {50, 48, 46, 44, 42, 40, 38, 36};
#define CLOCK 2
#define READ_WRITE 34

void setup() {
  for(int n = 0; n < 16; n += 1){
    pinMode(ADDR[n], INPUT);
  }
  for(int n = 0; n < 8; n += 1){
    pinMode(DATA[n], INPUT);
  }
  pinMode(CLOCK, INPUT);
  pinMode(READ_WRITE, INPUT);
  
  attachInterrupt(digitalPinToInterrupt(CLOCK), onClock, RISING);
  
  Serial.begin(57600);

}

void onClock(){
  char output[15];
  
  unsigned int address = 0;
  for(int n = 0; n < 16; n += 1){
    int bit = digitalRead(ADDR[n]) ? 1 : 0;
    Serial.print(bit);
    address = (address << 1) + bit;
  }
  
  Serial.print("   ");
  
  unsigned int data = 0;
  for(int n = 0; n < 8; n += 1){
    int bit = digitalRead(DATA[n]) ? 1 : 0;
    data = (data << 1) + bit;
    Serial.print(bit);
  }

  sprintf(output, "  %04x %c %02x", address, digitalRead(READ_WRITE) ? 'r' : 'w', data);
  
  Serial.println(output);
}

void loop() {
 
}

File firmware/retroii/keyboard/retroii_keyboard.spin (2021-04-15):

''*******************************
''* keyboard  9/2019                                                                    *
''* Author: Jon Thomoasson                                                              *
''* Description: firmware that runs on the keyboard processor for the RETRO ][ computer * 
''*******************************
''
''
CON
    _clkmode  = xtal1 + pll16x
    _xinfreq  = 5_000_000
    rx = 31
    tx = 30
    NUM        = %100
    RepeatRate = 40
    SDA_pin = 15
    SCL_pin = 14
    Bitrate = 900_000
    SLAVE_ID = $42
    MODE_REG = 29
    TX_FLAG = 26    'I2C register set when there's a byte being transmitted
    RX_FLAG = 27    'I2C register set when byte is received at video processor
    TX_DATA = 28    'I2C register which holds the byte being transmitted
    REG_FLAG = $FA  'this value indicates that the tx_flag or rx_flag is set
    RX_READY = 25   'this register set when video processor ready to receive
    CMD_FLAG = 24   'I2C register used to send commands to video processor
    CMD_RESET = $EA 'this value tells the video processor to reset the 6502
    CMD_RETROII = $BD 'command to set video mode to retroii mode
    CMD_DONE = $AC  'this value is an acknowledgement that the command has finished
    TXRX_TIMEOUT = 10_000
    CMD_REG = 22    'register for sending commands to the other processor
    CMD_DEBUG = $F1 'command tells video processor to toggle the debug screen
    COLOR_REG = 21
    CMD_CHANGE_COLOR = $B3
    
    {CLOCKS}
    'Btn_Phi2 = 11
    Prop_Phi2 = 12 'Clock generator output Phi0/Phi2 pin P12 - physical pin 17
    Prop_Phi1 = 16 'Phi1 to pin P15 - physical pin 20 (originally RDY) - cut trace and wire to H2 pin 5
    Prop_Q3 = 13 '2MHz clock signal for peripheral cards slots - used by floppy uController
    Prop_Q3_Inv = 11 'inverse Q3 signal
    MAX_CLOCK = 8 'the maximum frequency in MHz that we'll overclock
    CLOCK_REG = 23 'i2c register to hold clock value
    
    {SOFT SWITCHES}
    SS_LOW = 4
    SS_HIGH = 7
    SS_REG = 30
    
    {RESET}
    RESET_pin = 24
    RESET_PERIOD  = 20_000_000 '1/2 second
    
    {KEYBOARD RETRO][}
    Strobe = 25
    K0 = 17
    K6 = 23
    KEY_REG = 31
    
    {MODES}
    MODE_MONITOR = 1
    MODE_RETROII = 2
    MODE_ASSEMBLER = 3
    MODE_SD_CARD_1 = 4 'disk selection
    MODE_SD_CARD_2 = 5 'program selection
    MODE_SD_CARD_3 = 6 'program download            
    
    {SD CARD}
    SD_PINS  = 0
    RESULTS_PER_PAGE = 56
    ROWS_PER_FILE = 4 'number of longs it takes to store 1 file name
    MAX_FILES = 300 'limiting to 300 for now due to memory limits
    FILE_BUF_SIZE = 256 'size of file buffer. can optimize this later on.
    LINE_BUF_SIZE = 10
    
    {FILE OPTIONS FOR MODE_SD_CARD_3}
    FILE_LOAD = 1
    FILE_RUN = 2  
OBJ 
    sd: "fsrw" 
    kb:   "keyboard"  
    ser: "FullDuplexSerial.spin"
    I2C : "I2C PASM driver v1.8od" 'od or open drain method requires pull ups on sda/scl lines. But may use this if I need a speed boost.
    'I2C : "I2C PASM driver v1.8pp" 
    'button: "Button"
DAT



VAR
    word key          
    long prog_download_option     
    long phi2_stack[20]  
    long cog_phi2 
    long soft_switches_old                                         
    long kb_output_data
    long current_mode
    long current_disk 'index of currently selected disk
    long current_clock 'current frequency in MHz for clock feeding the 6502
    long cat_track
    long cat_sector
    {sd card}
    byte tbuf[14]   '
    long file_count'
    long current_page'
    long last_page'
    long files[MAX_FILES * ROWS_PER_FILE] 'byte array to hold index and filename '
    byte file_buffer[FILE_BUF_SIZE]
    byte tslist_buffer[FILE_BUF_SIZE]
    byte line_buffer[LINE_BUF_SIZE]
    byte ss_override
    byte ss_text
    byte ss_mix
    byte ss_page2
    byte ss_hires
    byte ss_mask
    byte ss_text_override
    byte ss_page2_override
    byte ss_hires_override
    byte ss_mix_override
    long clock_freqs[10]
    long kb_clear
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

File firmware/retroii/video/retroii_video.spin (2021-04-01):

''------------------------------------------------------------------------------------------------
'' RETRO ][ video driver
''
'' Copyright (c) 2020 Jon Thomasson
''
''------------------------------------------------------------------------------------------------

CON

    _clkmode = xtal1 + pll16x
    _xinfreq = 5_000_000
    BasePin   = 16                          ' P16-P20 VGA
    SDA_pin = 29
    SCL_pin = 28      
    
    Line_Buffer_Size = 60
    TX_FLAG = 26    'I2C register set when there's a byte being transmitted
    RX_FLAG = 27    'I2C register set when byte is received at video processor
    CMD_FLAG = 24   'I2C register used to send commands to other processor
    CMD_RESET = $EA 'this value tells the processor to reset the 6502
    CMD_DONE = $AC  'this value is an acknowledgement that the command has finished
    CMD_RETROII = $BD 'command to set video mode to retroii mode
    TX_BYTE = 28    'I2C register which holds the byte being transmitted
    REG_FLAG = $FA  'this value indicates that the tx_flag or rx_flag is set                                  ' 
    RX_READY = 25   'I2C register set when ready  to receive from keyboard
    TXRX_TIMEOUT = 35_000
    CMD_REG = 22    'register for receiving commands from the other processor
    CMD_DEBUG = $F1 'command tells video processor to toggle the debug screen
    SS_REG = 30
    KEY_REG = 31
    SLAVE_ID = $42
    COLOR_REG = 21
    CMD_CHANGE_COLOR = $B3
    
    {DATA PINS}
    D0 = 0
    D7 = 7
    
    {CLOCK}
    CLOCK_REG = 23 'i2c register to hold clock value
    
    {ADDRESS PINS}
    A0 = 8
    A7 = 15
    A8 = 21
    A14 = 27
    A15 = 31
    
    {WRITE ENABLE PIN}
    WE = 30
    
    {MODES}
    MODE_REG = 29
    MODE_MONITOR = 1
    MODE_RETROII = 2
    MODE_ASSEMBLER = 3
    MODE_SD_CARD_1 = 4 'disk selection
    MODE_SD_CARD_2 = 5 'program selection
    MODE_SD_CARD_3 = 6 'program download 
    
    {FILE OPTIONS FOR MODE_SD_CARD_3}
    FILE_LOAD = 1
    FILE_RUN = 2   
                    '
    {RETROII_MODES}
    RETROII_TEXT = 1
    RETROII_HIRES = 2
    RETROII_LORES = 3
    RETROII_OFF = 0
    
    {PAGE_LOCATIONS}
    TEXT_PAGE1 = $400
    TEXT_PAGE2 = $800
    HIRES_PAGE1 = $2000
    HIRES_PAGE2 = $4000
    
    ROWS_PER_PAGE = 28

VAR
                                                                         
    long sync                               ' sync used by VGA routine

    long pos                                ' Global Screen-Pointer
    long bpos                               ' Global Screen-Pointer
    byte line_buffer[Line_Buffer_Size]
    long row_num
    byte ascii_buffer[16]
    byte cursor_x
    byte line_count
    long current_mode
    long retroii_mode
    long old_mode
    byte rx_error  
    long soft_switches
    byte ss_text
    byte ss_mix
    byte ss_page2
    byte ss_hires
    byte soft_switches_updated 
    long cog_soft_switches
    long cog_ss_stack[20]
    long cog_regs
    long cog_regs_stack[20]
    long prog_download_option
    long current_clock 'current frequency in Hz for clock feeding the 6502
    long old_clock 
    long clock_freqs[10]
    byte colors[7]
    long current_color
    byte display_debug
    byte old_display_debug
    byte update_debug
    byte frame_rate_started
    byte frame_rate_clear
    byte frame_rate_old
    byte frame_rate_new
    byte frame_counter
OBJ

    R2 : "r2_video.spin"
    slave : "I2C slave v1.2"

PUB Main 
    init
    repeat 
        case current_mode
            MODE_MONITOR: 
                run_monitor
            MODE_RETROII:
                run_retroii
            MODE_SD_CARD_1:
                run_sd_disk_select
            MODE_SD_CARD_2:
                run_sd_prog_select
            MODE_SD_CARD_3:
                run_sd_file_download
                
    
{{
Summary: Converts an ASCII character into its binary equivalent
Params: ascii: the ascii char to convert
Returns: binary: the binary number for the ascii char
}}
PRI ascii_2bin(ascii) | binary

    if ascii < 58           'if ascii number (dec 48-57)
        binary := ascii -48 'subtract 48 to get dec equivalent
    else
        binary := ascii -55 'else subtract 55 for ABCDEF 
    
    return binary
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

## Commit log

2019-04-12 added card edge peripheral connector footprint and 3d model.
    [c-5530841-5-b-3d.stp, peripheral_io.sch]
2019-04-13 added audio logarithmic volume control
    [91A1A-B24.stp, serial_io_audio.sch]
2019-04-13 added 8ohm speaker footprint and 3d model
    [CUI_CVS-1708.step, serial_io_audio.sch]
2019-04-14 added audio connector footprints/3d models.
    [serial_io_audio.sch]
2019-04-14 added optional bypass caps for peripheral slots
    [peripheral_io.sch]
2019-04-15 added vga dsub-15 footprint and 3d model
    [Sicd15s13e6gv00lf.stp, peripheral_io.sch, power_supply.sch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]
2019-04-19 added 3d model/footprints for 100uH and 20uH inductors.
    [SRP1770TA.stp, power_supply.sch]
2019-04-20 added tactile switches 3d models, footprints, symbols.
    [sd_card_keyboard.sch, video.sch]
2019-04-21 finished footprints/models for power supply caps
    [power_supply.sch, sd_card_keyboard.sch, serial_io_audio.sch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]
2019-04-23 added ram plcc84 footprint and 3d model.
    [cpu_ram_rom.sch]
2019-04-28 footprint finalizations.
    [peripheral_io.sch, power_supply.sch, retroii.kicad_pcb]
2019-04-30 to220-5 3d model and footprint.
    [TO-220-5.STEP, video.sch]
2019-05-02 replaced 558 quad timer with 2 556 dual timers.
    [cpu_ram_rom.sch, power_supply.sch, serial_io_audio.sch]
2019-05-03 added series resistors for prop 5v interface pins.
    [retroii.kicad_pcb, sd_card_keyboard.sch, serial_io_audio.sch]
2019-05-03 added prop_q3 to peripheral slot connections.
    [peripheral_io.sch, retroii.kicad_pcb, retroii.sch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]
2019-05-03 fixed headphone jack footprint errors
    [retroii.kicad_pcb]
2019-05-05 added support for lm2576 adjustable version
    [power_supply.sch, retroii.kicad_pcb]
2019-05-11 laid out peripheral slots
    [retroii.kicad_pcb]
2019-05-12 started layout of sd/keyboard/video/ram/rom/cpu
    [retroii.kicad_pcb]
2019-05-12 started laying out address decoding
    [retroii.kicad_pcb]
2019-05-13 more layout
    [retroii.kicad_pcb]
2019-05-14 address decoding layout
    [retroii.kicad_pcb]
2019-05-14 layout ram/video/sd/keyboard
    [retroii.kicad_pcb]
2019-05-19 beginning power supply layout
    [retroii.kicad_pcb]
2019-05-20 added more in/out caps for psu. finished initial layout of psu.
    [cpu_ram_rom.sch, power_supply.sch, retroii.kicad_pcb]
2019-05-21 started audio/cassette in/out layout
    [retroii.kicad_pcb]
2019-05-23 audio cassette in/out layout
    [retroii.kicad_pcb]
2019-05-23 added footprint for 9 position dsub joysticks
    [L17H222X131.stp]
2019-05-23 added footprint for stacked 15 pos dsub for pc port joysticks.
    [178-015-513.STEP]
2019-05-23 fixed dsub 15 footprint with correct pin numbers
2019-05-23 replaced db9/db15 connectors with stacked versions
    [179-015-513.STEP, 189-015-513.STEP, retroii.kicad_pcb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]
2019-05-24 laying out audio
    [retroii.kicad_pcb, serial_io_audio.sch]
2019-05-25 layout mods for serial io
    [retroii.kicad_pcb, serial_io_audio.sch]
2019-05-25 finished initial layout
    [retroii.kicad_pcb]
2019-06-01 working on optimizing keyboard layout
    [retroii.kicad_pcb, sd_card_keyboard.sch]
2019-06-03 modified prop layout to include jumpers for phi2, rdy, and dma.
    [cpu_ram_rom.sch, retroii.kicad_pcb, retroii.sch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]
2019-06-08 updated strobe/reset/keyboard connections
    [retroii.kicad_pcb, sd_card_keyboard.sch]
2019-06-12 keyboard/sd card propeller circuitry more or less in final position
    [retroii.kicad_pcb]
2019-06-13 more layout finalization on address decoding circuit
    [retroii.kicad_pcb]
2019-06-15 more keyboard circuit layout changes
    [retroii.kicad_pcb]
2019-06-15 more general layout (address decoding, timing, keyboard)
    [retroii.kicad_pcb]
2019-06-24 laying out audio/serial io
    [retroii.kicad_pcb]
2019-07-01 layout for audio/cassette in/out and serial
    [retroii.kicad_pcb]
2019-07-05 more layout changes on camping trip!
    [retroii.kicad_pcb]
2019-07-09 added m4 mounting holes
    [retroii.kicad_pcb, retroii.sch]
2019-07-10 finalizing edge cuts and mounting hole locations
    [retroii.kicad_pcb]
2019-07-12 started routing traces!
    [retroii.kicad_pcb]
2019-07-12 added a fuse
    [FUS_LITTELFUSE_370.step, power_supply.sch, retroii.kicad_pcb]
2019-07-13 routing power
    [retroii.kicad_pcb]
2019-07-13 routing power and peripheral slots
    [retroii.kicad_pcb]
2019-07-14 routed peripheral slots
    [retroii.kicad_pcb]
2019-07-14 routing audio and keyboard/sd interface
    [retroii.kicad_pcb, sd_card_keyboard.sch]
2019-07-15 keyboard routing
    [retroii.kicad_pcb]
2019-07-16 routed sd card
    [retroii.kicad_pcb]
2019-07-19 more keyboard/reset/sd card layout
    [retroii.kicad_pcb]
2019-07-19 finished routing keyboard/sd card/reset module
    [retroii.kicad_pcb]
2019-07-26 started work on power supply routing
    [retroii-B_Cu.gbr, retroii-B_Mask.gbr, retroii-B_Paste.gbr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]
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2019-07-27 first pass of routing done!
    [power_supply.sch, sd_card_keyboard.sch]
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2019-08-06 added gerber
    [retroii-B_Cu.gbl, retroii-B_Mask.gbs, retroii-B_SilkS.gbo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]
2019-08-06 testing different gerber format.
    [retroii-B_Cu.gbr, retroii-B_Mask.gbr, retroii-B_SilkS.gbr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]
2019-08-06 trying another gerber layout for jlcpcb
    [retroii-B_Cu.gbr, retroii-B_Mask.gbr, retroii-B_SilkS.gbr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]
2019-08-06 redoing gerber format. Going back to original.
    [retroii-B_Cu.gbl, retroii-B_Mask.gbs, retroii-B_SilkS.gbo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]
2019-08-23 basic ram test to test reading/writing from prop video module to video ram.
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2019-09-25 fixed pinout for arduino peripheral card. verified tested and working!
    [_6502-monitor.ino]
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2019-09-29 fixed bug with reading soft switches
    needed to set soft switches as inputs at initialization
    [retroii_keyboard.spin]
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2019-10-12 fixing rx_flag reset error
    [retroii_video.spin]
2019-10-14 fixed rx bug for disk parser
    [retroii_keyboard.spin, retroii_video.spin]
2019-10-18 fixing bugs with file upload
    [retroii_keyboard.spin, retroii_video.spin]
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2019-12-07 fixing hires bug - left side of screen cuts off
    [retroii_video.spin]
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2019-12-07 fixed mem monitor bug
    [retroii_video.spin]
2019-12-07 fixed some vga glitching and clear screen when switching retroii video modes
    [retroii_video.spin]
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2020-02-11 starting on PixelByte function to replace Pixel function for hires mode.
    [r2_video.spin, retroii_video.spin]
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2020-02-21 fixed a soft switch bug for hires mode
    [retroii_video.spin]
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2020-02-22 optimized char routine and fixed cursor bug
    [r2_video.spin, retroii_video.spin]
2020-02-24 fixed some bugs with lores mode
    [r2_video.spin]
2020-02-25 fixed glitching bug for lores mode
    [r2_video.spin, retroii_video.spin]
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2020-03-06 fixed bug with characters coming over when switch from retroii mode to monitor
    [retroii_keyboard.spin]
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2020-03-10 fixed clock debug screen flicker
    [retroii_video.spin]
2020-03-10 fixing toggle debug glitch
    [retroii_video.spin]
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2020-03-14 fixed color toggle bug
    [r2_video.spin, retroii_video.spin]
2020-03-21 fixing glitch where hires pasm routine running in other modes.
    [r2_video.spin, retroii_video.spin]
2020-03-26 fixed bug when switching between hires and other retroii modes
    [r2_video.spin, retroii_video.spin]
2020-03-26 fixed bug switching from hires to another mode
    [retroii_video.spin]
2020-03-28 fixed pasm mix mode
    [r2_video.spin]
2020-03-29 fixed formatting on inverse/flashing text in mix pasm mode
    [r2_video.spin]
2020-03-30 updated auto refresh bug for debug clock
    [retroii_video.spin]
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2020-04-01 fixing cursor error for pasm mix mode
    [r2_video.spin]
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2020-04-05 fixed counter flash speed for mixed pasm
    [r2_video.spin]
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2020-04-21 case design - fixed a few bugs
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2020-04-28 case - fixed formatting
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2020-09-24 fixing lores mode with new vga driver
    [r2_video.spin]
2020-10-18 fixing text mode not displaying white in color mode.
    [r2_video.spin]
2021-02-28 fixing clock generator to enable floppy drive
    [retroii_keyboard.spin]
2021-03-31 fixing compile/timing issues after floppy merge
    [retroii_keyboard.spin]
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2021-04-04 adding some updates to fix random language/ram card fault during init.
    [retroii_keyboard.spin]
2021-04-15 taking jitter out of Q3, PHI1/2 clocks. Using 1X PLL multiplier.
    [retroii_keyboard.spin]
2021-04-27 Create retroii_case_extension_v2 v2.stl
    adding stl file for 3d printing a case extension to accommodate tall peripheral cards.
    [retroii_case_extension_v2 v2.stl]
